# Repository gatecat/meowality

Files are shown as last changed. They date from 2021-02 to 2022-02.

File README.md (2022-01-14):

# Meowality - Kria SoM mixed reality
 
 - Kria K26 SoM with UltraScale+ FPGA
     + 4x 1.5GHz Cortex A53
     + 4GB PS DDR4
     + 256k UltraScale+ logic cells;
     + hard H.264/H.265 IP
 - 2x LPM035M407B 1440x1600 90fps LCDs (2x4-lane MIPI DSI)
 - 2x 4-lane Pi cam connector intended for iMX477 (4k 60fps+)
 - 4-lane mini-Displayport connector on fabric GTH, up to HBR3/DP1.4
 - 2-lane M.2 connector for WiFi module on PS GTR
 - USB type-C connector with USB 2 PHY on PS MIO and USB 3 on PS GTR
 - USB PD power
 - ICM-20789 IMU
 - MMC5983 magnetometer
 - microSD card
 - 5x RGB LED
 - JTAG & UART on Harting 10B-1 connector

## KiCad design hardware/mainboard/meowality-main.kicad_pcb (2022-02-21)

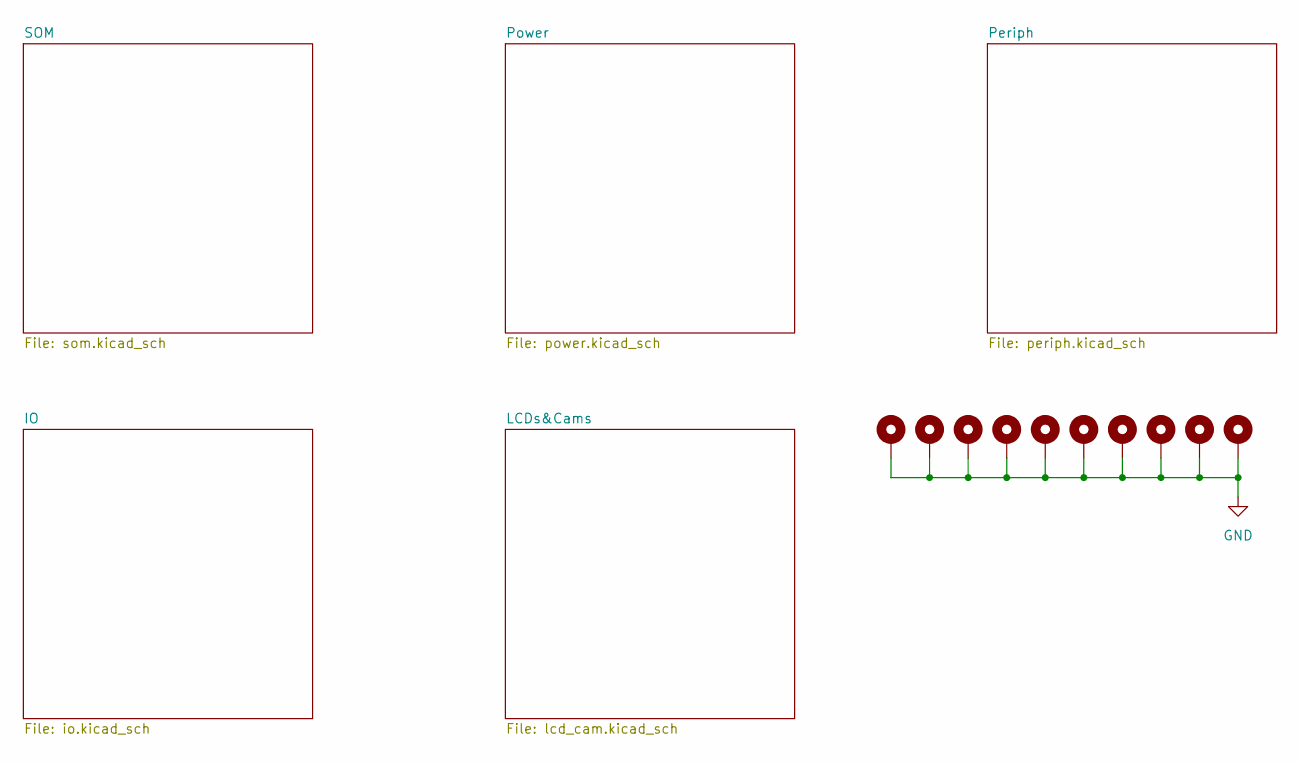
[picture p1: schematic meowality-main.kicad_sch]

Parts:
H1, H2, H3, H4, H5, H6, H7, H8, H9, H10: MountingHole_Pad; MountingHole_2.7mm_M2.5_Pad_Via

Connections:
GND: H1.1, H2.1, H3.1, H4.1, H5.1, H6.1, H7.1, H8.1, H9.1, H10.1; also elsewhere on the board

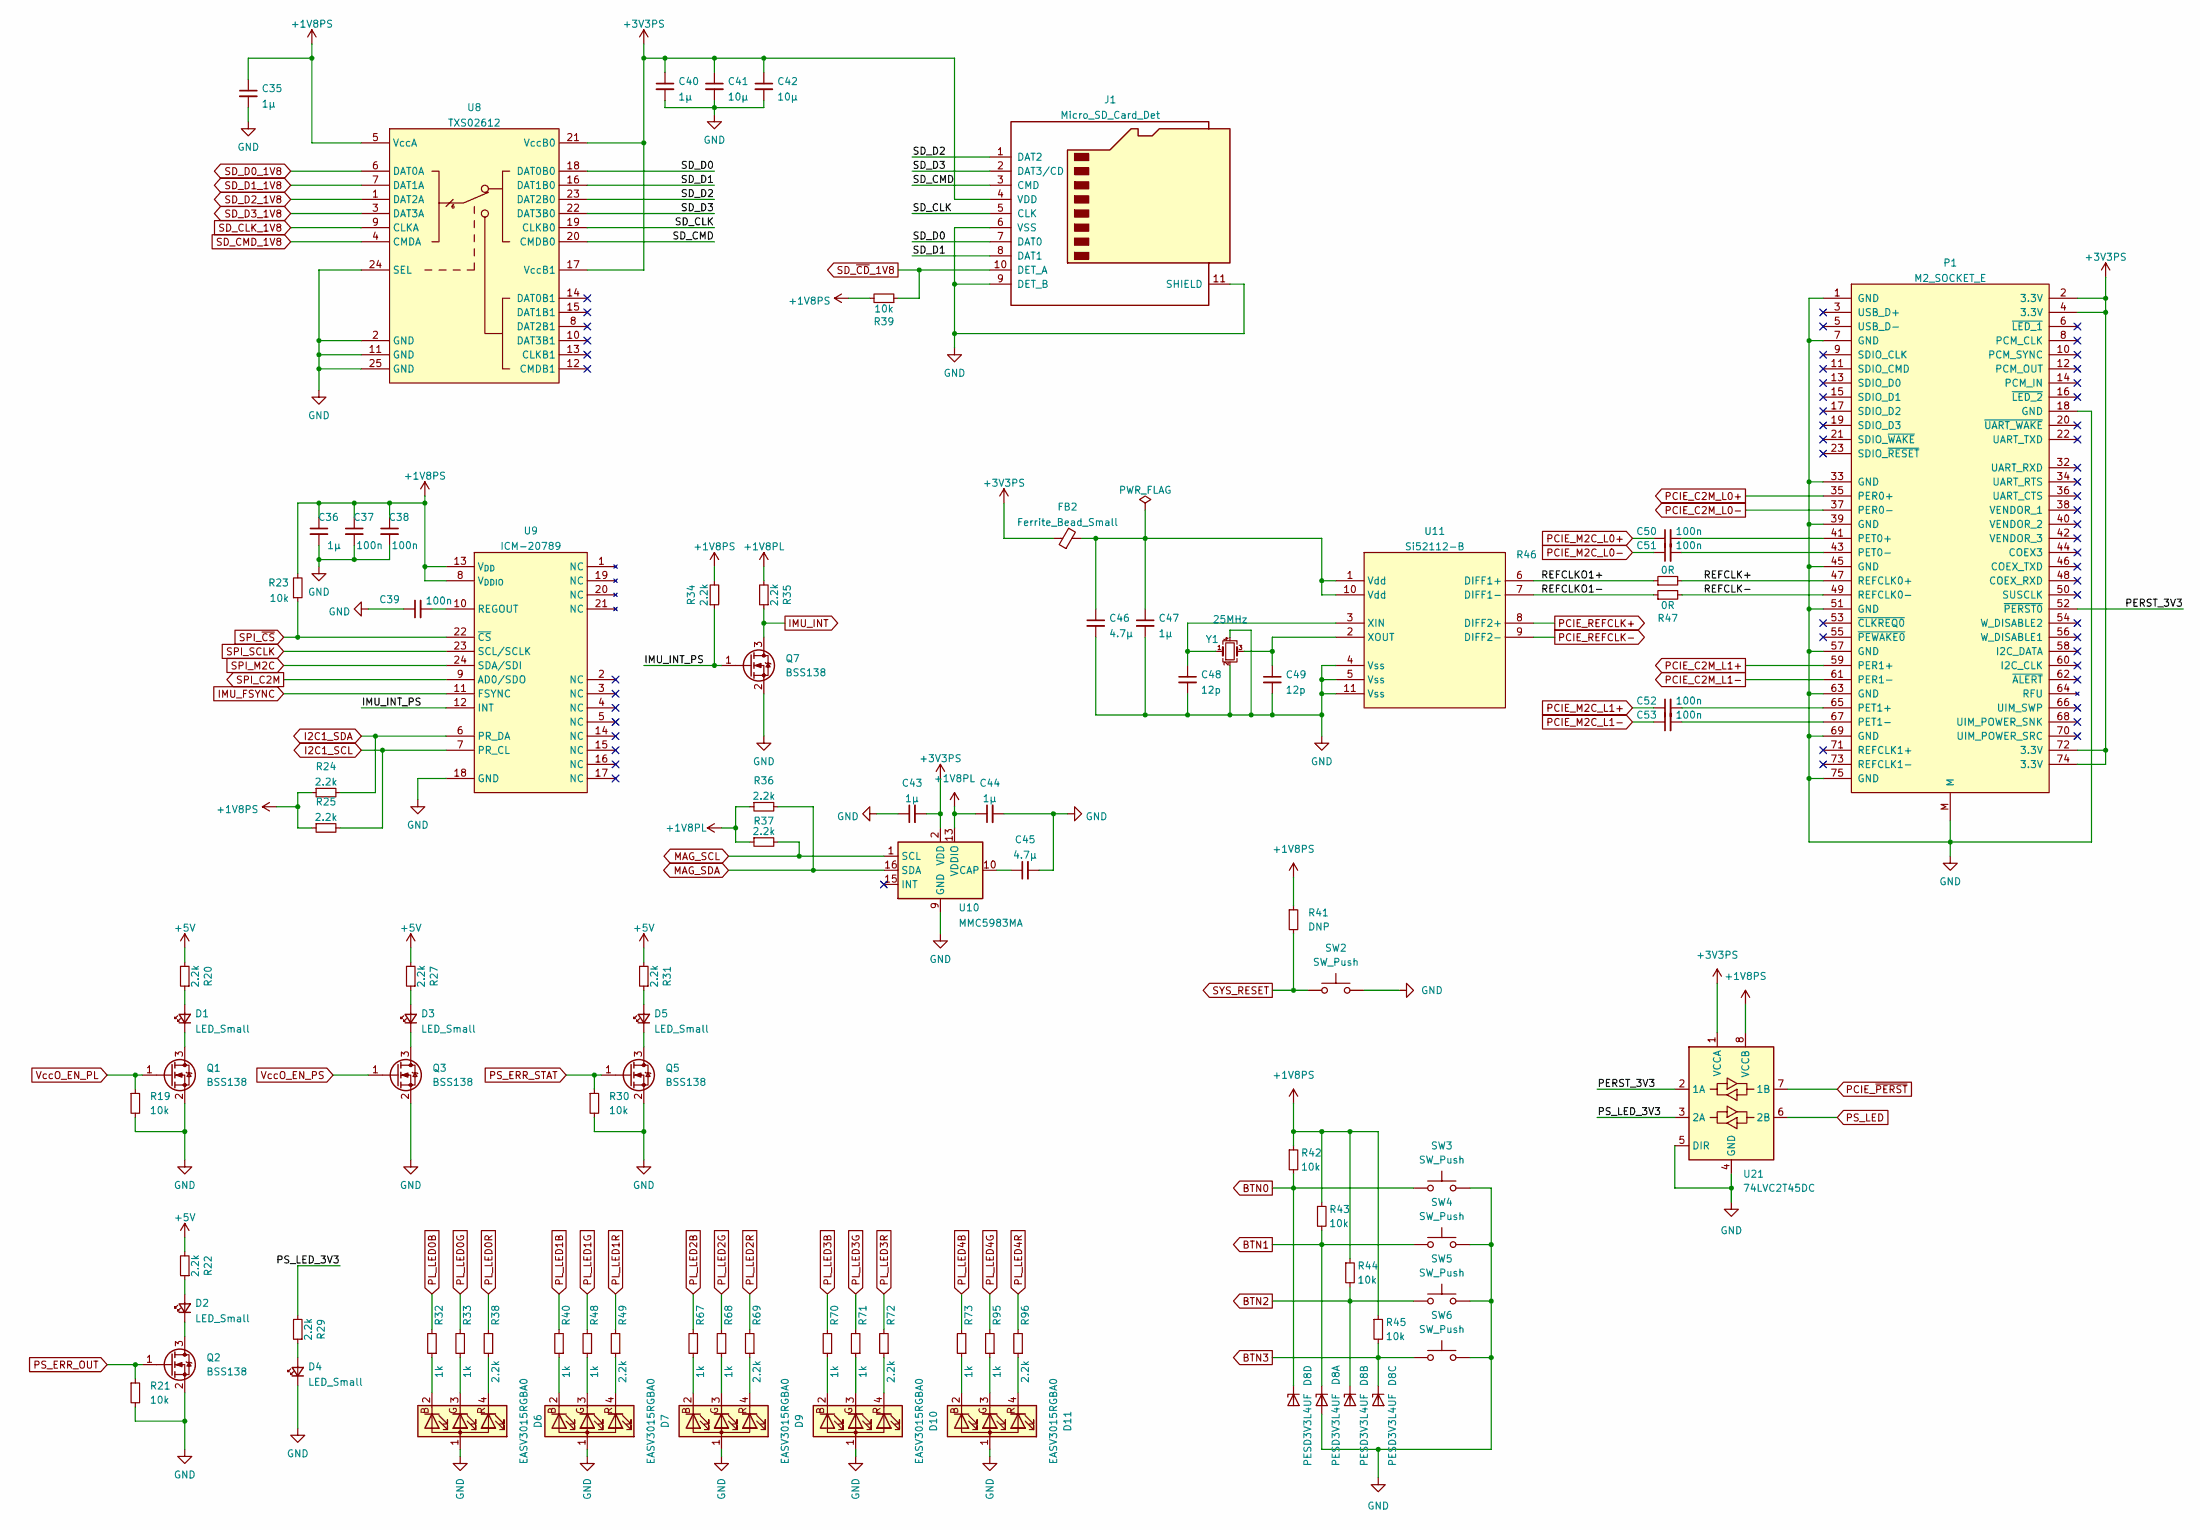
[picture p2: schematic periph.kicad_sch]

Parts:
C35, C36, C40, C43, C44, C47: 1µ; C_0603_1608Metric
C37, C38, C39, C50, C51, C52, C53: 100n; C_0402_1005Metric
C41, C42: 10µ; C_1206_3216Metric
C45, C46: 4.7µ; C_0603_1608Metric
C48, C49: 12p; C_0402_1005Metric
D1, D2, D3, D4, D5: LED_Small; LED_0603_1608Metric
D6, D7, D9, D10, D11: EASV3015RGBA0; EASV3015R
D8: PESD3V3L4UF; SOT-886
FB2: Ferrite_Bead_Small; L_0603_1608Metric
J1: Micro_SD_Card_Det; microSD_HC_Hirose_DM3AT-SF-PEJM5
P1: M2_SOCKET_E; 2199230-4
Q1, Q2, Q3, Q5, Q7: BSS138; SOT-23
R19, R21, R23, R30, R39, R42, R43, R44, R45: 10k; R_0402_1005Metric
R20, R22, R24, R25, R27, R29, R31, R34, R35, R36, R37, R38, R49, R69, R72, R96: 2.2k; R_0402_1005Metric
R32, R33, R40, R48, R67, R68, R70, R71, R73, R95: 1k; R_0402_1005Metric
R41: DNP; R_0402_1005Metric
R46, R47: 0R; R_0402_1005Metric
SW2, SW3, SW4, SW5, SW6: SW_Push; SW_SPST_B3S-1000
U8: TXS02612; WQFN-24-1EP_4x4mm_P0.5mm_EP2.45x2.45mm
U9: ICM-20789; InvenSense_QFN-24_4x4mm_P0.5mm
U10: MMC5983MA; LGA-16_3x3mm_P0.5mm
U11: Si52112-B; TDFN10_3x3mm_p0.5mm
U21: 74LVC2T45DC; X2SON-8_1.4x1mm_P0.35mm
Y1: 25MHz; Crystal_SMD_3225-4Pin_3.2x2.5mm

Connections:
+1V8PL: C44.1, R35.2, R36.1, R37.1, U10.13 (VDDIO); also elsewhere on the board
+1V8PS: C35.1, C36.1, C37.1, C38.1, R23.2, R24.1, R25.1, R34.2, R39.2, R41.1, R42.1, R43.1, R44.1, R45.1, U8.5 (VccA), U9.8 (V_{DDIO}), U9.13 (V_{DD}), U21.8 (VCCB); also elsewhere on the board
+3V3PS: C40.1, C41.1, C42.1, C43.2, FB2.1, J1.4 (VDD), P1.2 (3.3V), P1.4 (3.3V), P1.72 (3.3V), P1.74 (3.3V), U8.17 (VccB1), U8.21 (VccB0), U10.2 (VDD), U21.1 (VCCA); also elsewhere on the board
+5V: R20.2, R22.2, R27.2, R31.2; also elsewhere on the board
/Periph/IMU_INT_PS: Q7.1 (G), R34.1, U9.12 (INT)
/Periph/PERST_3V3: P1.52 (~PERST0), U21.2 (1A)
/Periph/PS_LED_3V3: R29.2, U21.3 (2A)
/Periph/REFCLK+: P1.47 (REFCLK0+), R46.2
/Periph/REFCLK-: P1.49 (REFCLK0-), R47.2
/Periph/REFCLKO1+: R46.1, U11.6 (DIFF1+)
/Periph/REFCLKO1-: R47.1, U11.7 (DIFF1-)
/Periph/SD_CLK: J1.5 (CLK), U8.19 (CLKB0)
/Periph/SD_CMD: J1.3 (CMD), U8.20 (CMDB0)
/Periph/SD_D0: J1.7 (DAT0), U8.18 (DAT0B0)
/Periph/SD_D1: J1.8 (DAT1), U8.16 (DAT1B0)
/Periph/SD_D2: J1.1 (DAT2), U8.23 (DAT2B0)
/Periph/SD_D3: J1.2 (DAT3/CD), U8.22 (DAT3B0)
BTN0: D8.6 (K4), R42.2, SW3.1; also elsewhere on the board
BTN1: D8.1 (K1), R43.2, SW4.1; also elsewhere on the board
BTN2: D8.3 (K2), R44.2, SW5.1; also elsewhere on the board
BTN3: D8.4 (K3), R45.2, SW6.1; also elsewhere on the board
GND: C35.2, C36.2, C37.2, C38.2, C39.1, C40.2, C41.2, C42.2, C43.1, C44.2, C45.2, C46.2, C47.2, C48.2, C49.2, D4.1 (K), D6.1 (A), D7.1 (A), D8.2 (A), D8.5 (A), D9.1 (A), D10.1 (A), D11.1 (A), J1.6 (VSS), J1.9 (DET_B), J1.11 (SHIELD), P1.1 (GND), P1.7 (GND), P1.18 (GND), P1.33 (GND), P1.39 (GND), P1.45 (GND), P1.51 (GND), P1.57 (GND), P1.63 (GND), P1.69 (GND), P1.75 (GND), P1.M, Q1.2 (S), Q2.2 (S), Q3.2 (S), Q5.2 (S), Q7.2 (S), R19.2, R21.2, R30.2, SW2.2, SW3.2, SW4.2, SW5.2, SW6.2, U8.2 (GND), U8.11 (GND), U8.24 (SEL), U8.25 (GND), U9.18 (GND), U10.9 (GND), U10.11 (GND), U11.4 (Vss), U11.5 (Vss), U11.11 (Vss), U21.4 (GND), U21.5 (DIR), Y1.2, Y1.4; also elsewhere on the board
I2C1_SCL: R25.2, U9.7 (PR_CL); also elsewhere on the board
I2C1_SDA: R24.2, U9.6 (PR_DA); also elsewhere on the board
IMU_FSYNC: U9.11 (FSYNC); also elsewhere on the board
IMU_INT: Q7.3 (D), R35.1; also elsewhere on the board
MAG_SCL: R37.2, U10.1 (SCL); also elsewhere on the board
MAG_SDA: R36.2, U10.16 (SDA); also elsewhere on the board
unnamed: C39.2, U9.10 (REGOUT)
unnamed: C45.1, U10.10 (CAP)
unnamed: C46.1, C47.1, FB2.2, U11.1 (Vdd), U11.10 (Vdd)
unnamed: C48.1, U11.3 (XIN), Y1.1
unnamed: C49.1, U11.2 (XOUT), Y1.3
unnamed: C50.2, P1.41 (PET0+)
unnamed: C51.2, P1.43 (PET0-)
unnamed: C52.2, P1.65 (PET1+)
unnamed: C53.2, P1.67 (PET1-)
unnamed: D1.1 (K), Q1.3 (D)
unnamed: D1.2 (A), R20.1
unnamed: D2.1 (K), Q2.3 (D)
unnamed: D2.2 (A), R22.1
unnamed: D3.1 (K), Q3.3 (D)
unnamed: D3.2 (A), R27.1
unnamed: D4.2 (A), R29.1
unnamed: D5.1 (K), Q5.3 (D)
unnamed: D5.2 (A), R31.1
unnamed: D6.2 (BK), R32.1
unnamed: D6.3 (GK), R33.1
unnamed: D6.4 (RK), R38.1
unnamed: D7.2 (BK), R40.1
unnamed: D7.3 (GK), R48.1
unnamed: D7.4 (RK), R49.1
unnamed: D9.2 (BK), R67.1
unnamed: D9.3 (GK), R68.1
unnamed: D9.4 (RK), R69.1
unnamed: D10.2 (BK), R70.1
unnamed: D10.3 (GK), R71.1
unnamed: D10.4 (RK), R72.1
unnamed: D11.2 (BK), R73.1
unnamed: D11.3 (GK), R95.1
unnamed: D11.4 (RK), R96.1
PCIE_C2M_L0+: P1.35 (PER0+); also elsewhere on the board
PCIE_C2M_L0-: P1.37 (PER0-); also elsewhere on the board
PCIE_C2M_L1+: P1.59 (PER1+); also elsewhere on the board
PCIE_C2M_L1-: P1.61 (PER1-); also elsewhere on the board
PCIE_M2C_L0+: C50.1; also elsewhere on the board
PCIE_M2C_L0-: C51.1; also elsewhere on the board
PCIE_M2C_L1+: C52.1; also elsewhere on the board
PCIE_M2C_L1-: C53.1; also elsewhere on the board
PCIE_REFCLK+: U11.8 (DIFF2+); also elsewhere on the board
PCIE_REFCLK-: U11.9 (DIFF2-); also elsewhere on the board
PCIE_~PERST: U21.7 (1B); also elsewhere on the board
PL_LED0B: R32.2; also elsewhere on the board
PL_LED0G: R33.2; also elsewhere on the board
PL_LED0R: R38.2; also elsewhere on the board
PL_LED1B: R40.2; also elsewhere on the board
PL_LED1G: R48.2; also elsewhere on the board
PL_LED1R: R49.2; also elsewhere on the board
PL_LED2B: R67.2; also elsewhere on the board
PL_LED2G: R68.2; also elsewhere on the board
PL_LED2R: R69.2; also elsewhere on the board
PL_LED3B: R70.2; also elsewhere on the board
PL_LED3G: R71.2; also elsewhere on the board
PL_LED3R: R72.2; also elsewhere on the board
PL_LED4B: R73.2; also elsewhere on the board
PL_LED4G: R95.2; also elsewhere on the board
PL_LED4R: R96.2; also elsewhere on the board
PS_ERR_OUT: Q2.1 (G), R21.1; also elsewhere on the board
PS_ERR_STAT: Q5.1 (G), R30.1; also elsewhere on the board
PS_LED: U21.6 (2B); also elsewhere on the board
SD_CLK_1V8: U8.9 (CLKA); also elsewhere on the board
SD_CMD_1V8: U8.4 (CMDA); also elsewhere on the board
SD_D0_1V8: U8.6 (DAT0A); also elsewhere on the board
SD_D1_1V8: U8.7 (DAT1A); also elsewhere on the board
SD_D2_1V8: U8.1 (DAT2A); also elsewhere on the board
SD_D3_1V8: U8.3 (DAT3A); also elsewhere on the board
SD_~CD_1V8: J1.10 (DET_A), R39.1; also elsewhere on the board
SPI_C2M: U9.9 (AD0/SDO); also elsewhere on the board
SPI_M2C: U9.24 (SDA/SDI); also elsewhere on the board
SPI_SCLK: U9.23 (SCL/SCLK); also elsewhere on the board
SPI_~CS: R23.1, U9.22 (~CS); also elsewhere on the board
SYS_RESET: R41.2, SW2.1; also elsewhere on the board
VccO_EN_PL: Q1.1 (G), R19.1; also elsewhere on the board
VccO_EN_PS: Q3.1 (G); also elsewhere on the board

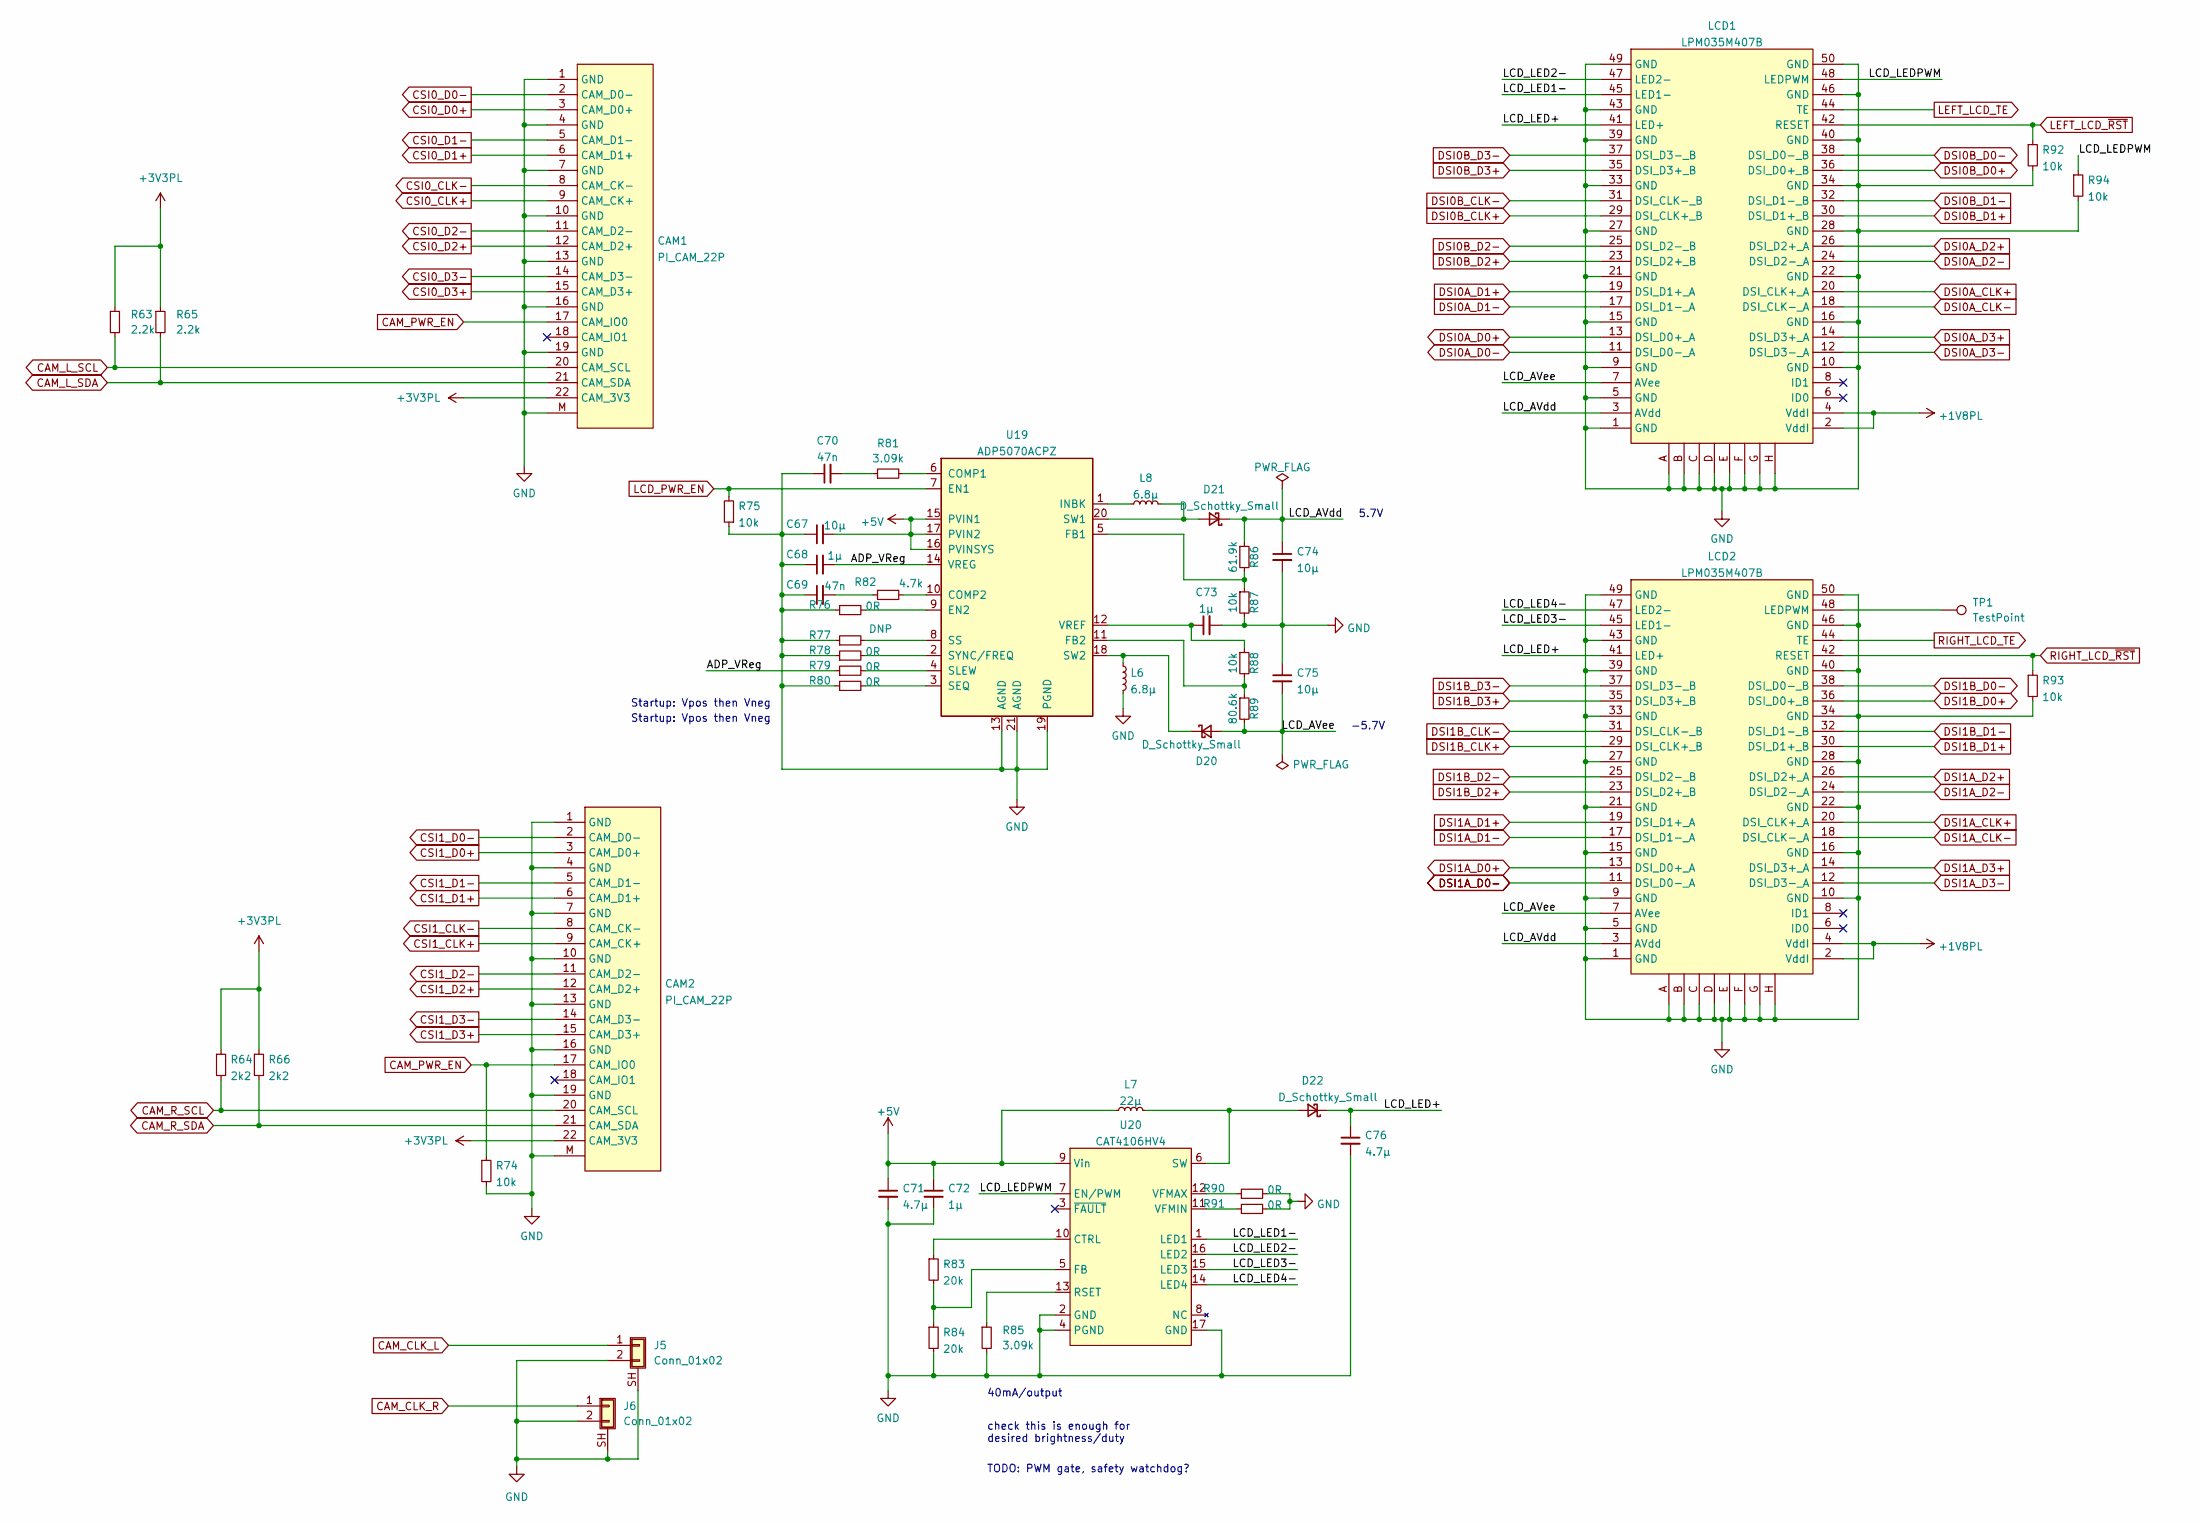
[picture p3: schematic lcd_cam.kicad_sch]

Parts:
C67, C74, C75: 10µ; C_1206_3216Metric
C68, C72, C73: 1µ; C_0603_1608Metric
C69, C70: 47n; C_0402_1005Metric
C71, C76: 4.7µ; C_0603_1608Metric
CAM1, CAM2: PI_CAM_22P; 54548-2271
D20, D21, D22: D_Schottky_Small; D_SMA
J5, J6: Conn_01x02; TE-292227-2
L6, L8: 6.8µ; L_Taiyo-Yuden_NR-50xx
L7: 22µ; L_Taiyo-Yuden_NR-50xx
LCD1, LCD2: LPM035M407B; 245863060104829
R63, R65: 2.2k; R_0402_1005Metric
R64, R66: 2k2; R_0402_1005Metric
R74, R75, R87, R88, R92, R93, R94: 10k; R_0402_1005Metric
R76, R78, R79, R80, R90, R91: 0R; R_0402_1005Metric
R77: DNP; R_0402_1005Metric
R81, R85: 3.09k; R_0402_1005Metric
R82: 4.7k; R_0402_1005Metric
R83, R84: 20k; R_0402_1005Metric
R86: 61.9k; R_0402_1005Metric
R89: 80.6k; R_0402_1005Metric
TP1: TestPoint; TestPoint_Pad_D2.0mm
U19: ADP5070ACPZ; QFN-20-1EP_4x4mm_P0.5mm_EP2.6x2.6mm
U20: CAT4106HV4; QFN-16-1EP_4x4mm_P0.65mm_EP2.1x2.1mm

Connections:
+1V8PL: LCD1.2 (VddI), LCD1.4 (VddI), LCD2.2 (VddI), LCD2.4 (VddI); also elsewhere on the board
+3V3PL: CAM1.22 (CAM_3V3), CAM2.22 (CAM_3V3), R63.1, R64.1, R65.1, R66.1; also elsewhere on the board
+5V: C67.2, C71.1, C72.1, L7.1, U19.15 (PVIN1), U19.16 (PVINSYS), U19.17 (PVIN2), U20.9 (Vin); also elsewhere on the board
/LCDs&Cams/ADP_VReg: C68.2, R79.1, U19.14 (VREG)
/LCDs&Cams/LCD_AVdd: C74.1, D21.1 (K), LCD1.3 (AVdd), LCD2.3 (AVdd), R86.1
/LCDs&Cams/LCD_AVee: C75.2, D20.2 (A), LCD1.7 (AVee), LCD2.7 (AVee), R89.2
/LCDs&Cams/LCD_LED1-: LCD1.45 (LED1-), U20.1 (LED1)
/LCDs&Cams/LCD_LED2-: LCD1.47 (LED2-), U20.16 (LED2)
/LCDs&Cams/LCD_LED3-: LCD2.45 (LED1-), U20.15 (LED3)
/LCDs&Cams/LCD_LED4-: LCD2.47 (LED2-), U20.14 (LED4)
/LCDs&Cams/LCD_LED+: C76.1, D22.1 (K), LCD1.41 (LED+), LCD2.41 (LED+)
/LCDs&Cams/LCD_LEDPWM: LCD1.48 (LEDPWM), R94.1, U20.7 (EN/PWM)
CAM_CLK_L: J5.1; also elsewhere on the board
CAM_CLK_R: J6.1; also elsewhere on the board
CAM_L_SCL: CAM1.20 (CAM_SCL), R63.2; also elsewhere on the board
CAM_L_SDA: CAM1.21 (CAM_SDA), R65.2; also elsewhere on the board
CAM_PWR_EN: CAM1.17 (CAM_IO0), CAM2.17 (CAM_IO0), R74.1; also elsewhere on the board
CAM_R_SCL: CAM2.20 (CAM_SCL), R64.2; also elsewhere on the board
CAM_R_SDA: CAM2.21 (CAM_SDA), R66.2; also elsewhere on the board
CSI0_CLK+: CAM1.9 (CAM_CK+); also elsewhere on the board
CSI0_CLK-: CAM1.8 (CAM_CK-); also elsewhere on the board
CSI0_D0+: CAM1.3 (CAM_D0+); also elsewhere on the board
CSI0_D0-: CAM1.2 (CAM_D0-); also elsewhere on the board
CSI0_D1+: CAM1.6 (CAM_D1+); also elsewhere on the board
CSI0_D1-: CAM1.5 (CAM_D1-); also elsewhere on the board
CSI0_D2+: CAM1.12 (CAM_D2+); also elsewhere on the board
CSI0_D2-: CAM1.11 (CAM_D2-); also elsewhere on the board
CSI0_D3+: CAM1.15 (CAM_D3+); also elsewhere on the board
CSI0_D3-: CAM1.14 (CAM_D3-); also elsewhere on the board
CSI1_CLK+: CAM2.9 (CAM_CK+); also elsewhere on the board
CSI1_CLK-: CAM2.8 (CAM_CK-); also elsewhere on the board
CSI1_D0+: CAM2.3 (CAM_D0+); also elsewhere on the board
CSI1_D0-: CAM2.2 (CAM_D0-); also elsewhere on the board
CSI1_D1+: CAM2.6 (CAM_D1+); also elsewhere on the board
CSI1_D1-: CAM2.5 (CAM_D1-); also elsewhere on the board
CSI1_D2+: CAM2.12 (CAM_D2+); also elsewhere on the board
CSI1_D2-: CAM2.11 (CAM_D2-); also elsewhere on the board
CSI1_D3+: CAM2.15 (CAM_D3+); also elsewhere on the board
CSI1_D3-: CAM2.14 (CAM_D3-); also elsewhere on the board
DSI0A_CLK+: LCD1.20 (DSI_CLK+_A); also elsewhere on the board
DSI0A_CLK-: LCD1.18 (DSI_CLK-_A); also elsewhere on the board
DSI0A_D0+: LCD1.13 (DSI_D0+_A); also elsewhere on the board
DSI0A_D0-: LCD1.11 (DSI_D0-_A); also elsewhere on the board
DSI0A_D1+: LCD1.19 (DSI_D1+_A); also elsewhere on the board
DSI0A_D1-: LCD1.17 (DSI_D1-_A); also elsewhere on the board
DSI0A_D2+: LCD1.26 (DSI_D2+_A); also elsewhere on the board
DSI0A_D2-: LCD1.24 (DSI_D2-_A); also elsewhere on the board
DSI0A_D3+: LCD1.14 (DSI_D3+_A); also elsewhere on the board
DSI0A_D3-: LCD1.12 (DSI_D3-_A); also elsewhere on the board
DSI0B_CLK+: LCD1.29 (DSI_CLK+_B); also elsewhere on the board
DSI0B_CLK-: LCD1.31 (DSI_CLK-_B); also elsewhere on the board
DSI0B_D0+: LCD1.36 (DSI_D0+_B); also elsewhere on the board
DSI0B_D0-: LCD1.38 (DSI_D0-_B); also elsewhere on the board
DSI0B_D1+: LCD1.30 (DSI_D1+_B); also elsewhere on the board
DSI0B_D1-: LCD1.32 (DSI_D1-_B); also elsewhere on the board
DSI0B_D2+: LCD1.23 (DSI_D2+_B); also elsewhere on the board
DSI0B_D2-: LCD1.25 (DSI_D2-_B); also elsewhere on the board
DSI0B_D3+: LCD1.35 (DSI_D3+_B); also elsewhere on the board
DSI0B_D3-: LCD1.37 (DSI_D3-_B); also elsewhere on the board
DSI1A_CLK+: LCD2.20 (DSI_CLK+_A); also elsewhere on the board
DSI1A_CLK-: LCD2.18 (DSI_CLK-_A); also elsewhere on the board
DSI1A_D0+: LCD2.13 (DSI_D0+_A); also elsewhere on the board
DSI1A_D0-: LCD2.11 (DSI_D0-_A); also elsewhere on the board
DSI1A_D1+: LCD2.19 (DSI_D1+_A); also elsewhere on the board
DSI1A_D1-: LCD2.17 (DSI_D1-_A); also elsewhere on the board
DSI1A_D2+: LCD2.26 (DSI_D2+_A); also elsewhere on the board
DSI1A_D2-: LCD2.24 (DSI_D2-_A); also elsewhere on the board
DSI1A_D3+: LCD2.14 (DSI_D3+_A); also elsewhere on the board
DSI1A_D3-: LCD2.12 (DSI_D3-_A); also elsewhere on the board
DSI1B_CLK+: LCD2.29 (DSI_CLK+_B); also elsewhere on the board
DSI1B_CLK-: LCD2.31 (DSI_CLK-_B); also elsewhere on the board
DSI1B_D0+: LCD2.36 (DSI_D0+_B); also elsewhere on the board
DSI1B_D0-: LCD2.38 (DSI_D0-_B); also elsewhere on the board
DSI1B_D1+: LCD2.30 (DSI_D1+_B); also elsewhere on the board
DSI1B_D1-: LCD2.32 (DSI_D1-_B); also elsewhere on the board
DSI1B_D2+: LCD2.23 (DSI_D2+_B); also elsewhere on the board
DSI1B_D2-: LCD2.25 (DSI_D2-_B); also elsewhere on the board
DSI1B_D3+: LCD2.35 (DSI_D3+_B); also elsewhere on the board
DSI1B_D3-: LCD2.37 (DSI_D3-_B); also elsewhere on the board
GND: C67.1, C68.1, C69.1, C70.1, C71.2, C72.2, C73.2, C74.2, C75.1, C76.2, CAM1.1 (GND), CAM1.4 (GND), CAM1.7 (GND), CAM1.10 (GND), CAM1.13 (GND), CAM1.16 (GND), CAM1.19 (GND), CAM1.M, CAM2.1 (GND), CAM2.4 (GND), CAM2.7 (GND), CAM2.10 (GND), CAM2.13 (GND), CAM2.16 (GND), CAM2.19 (GND), CAM2.M, J5.2, J5.SH (Shield), J6.2, J6.SH (Shield), L6.2, LCD1.1 (GND), LCD1.5 (GND), LCD1.9 (GND), LCD1.10 (GND), LCD1.15 (GND), LCD1.16 (GND), LCD1.21 (GND), LCD1.22 (GND), LCD1.27 (GND), LCD1.28 (GND), LCD1.33 (GND), LCD1.34 (GND), LCD1.39 (GND), LCD1.40 (GND), LCD1.43 (GND), LCD1.46 (GND), LCD1.49 (GND), LCD1.50 (GND), LCD1.A, LCD1.B, LCD1.C, LCD1.D, LCD1.E, LCD1.F, LCD1.G, LCD1.H, LCD2.1 (GND), LCD2.5 (GND), LCD2.9 (GND), LCD2.10 (GND), LCD2.15 (GND), LCD2.16 (GND), LCD2.21 (GND), LCD2.22 (GND), LCD2.27 (GND), LCD2.28 (GND), LCD2.33 (GND), LCD2.34 (GND), LCD2.39 (GND), LCD2.40 (GND), LCD2.43 (GND), LCD2.46 (GND), LCD2.49 (GND), LCD2.50 (GND), LCD2.A, LCD2.B, LCD2.C, LCD2.D, LCD2.E, LCD2.F, LCD2.G, LCD2.H, R74.2, R75.1, R76.1, R77.1, R78.1, R80.1, R84.2, R85.2, R87.2, R90.2, R91.2, R92.2, R93.2, R94.2, U19.13 (AGND), U19.19 (PGND), U19.21 (AGND), U20.2 (GND), U20.4 (PGND), U20.17 (GND); also elsewhere on the board
LCD_PWR_EN: R75.2, U19.7 (EN1); also elsewhere on the board
LEFT_LCD_TE: LCD1.44 (TE); also elsewhere on the board
LEFT_LCD_~RST: LCD1.42 (RESET), R92.1; also elsewhere on the board
unnamed: C69.2, R82.1
unnamed: C70.2, R81.1
unnamed: C73.1, R88.1, U19.12 (VREF)
unnamed: D20.1 (K), L6.1, U19.18 (SW2)
unnamed: D21.2 (A), L8.2, U19.20 (SW1)
unnamed: D22.2 (A), L7.2, U20.6 (SW)
unnamed: L8.1, U19.1 (INBK)
unnamed: LCD2.48 (LEDPWM), TP1.1
unnamed: R76.2, U19.9 (EN2)
unnamed: R77.2, U19.8 (SS)
unnamed: R78.2, U19.2 (SYNC/FREQ)
unnamed: R79.2, U19.4 (SLEW)
unnamed: R80.2, U19.3 (SEQ)
unnamed: R81.2, U19.6 (COMP1)
unnamed: R82.2, U19.10 (COMP2)
unnamed: R83.1, U20.10 (CTRL)
unnamed: R83.2, R84.1, U20.5 (FB)
unnamed: R85.1, U20.13 (RSET)
unnamed: R86.2, R87.1, U19.5 (FB1)
unnamed: R88.2, R89.1, U19.11 (FB2)
unnamed: R90.1, U20.12 (VFMAX)
unnamed: R91.1, U20.11 (VFMIN)
RIGHT_LCD_TE: LCD2.44 (TE); also elsewhere on the board
RIGHT_LCD_~RST: LCD2.42 (RESET), R93.1; also elsewhere on the board

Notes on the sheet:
40mA/output
TODO: PWM gate, safety watchdog?
check this is enough for desired brightness/duty
5.7V
Startup: Vpos then Vneg
-5.7V

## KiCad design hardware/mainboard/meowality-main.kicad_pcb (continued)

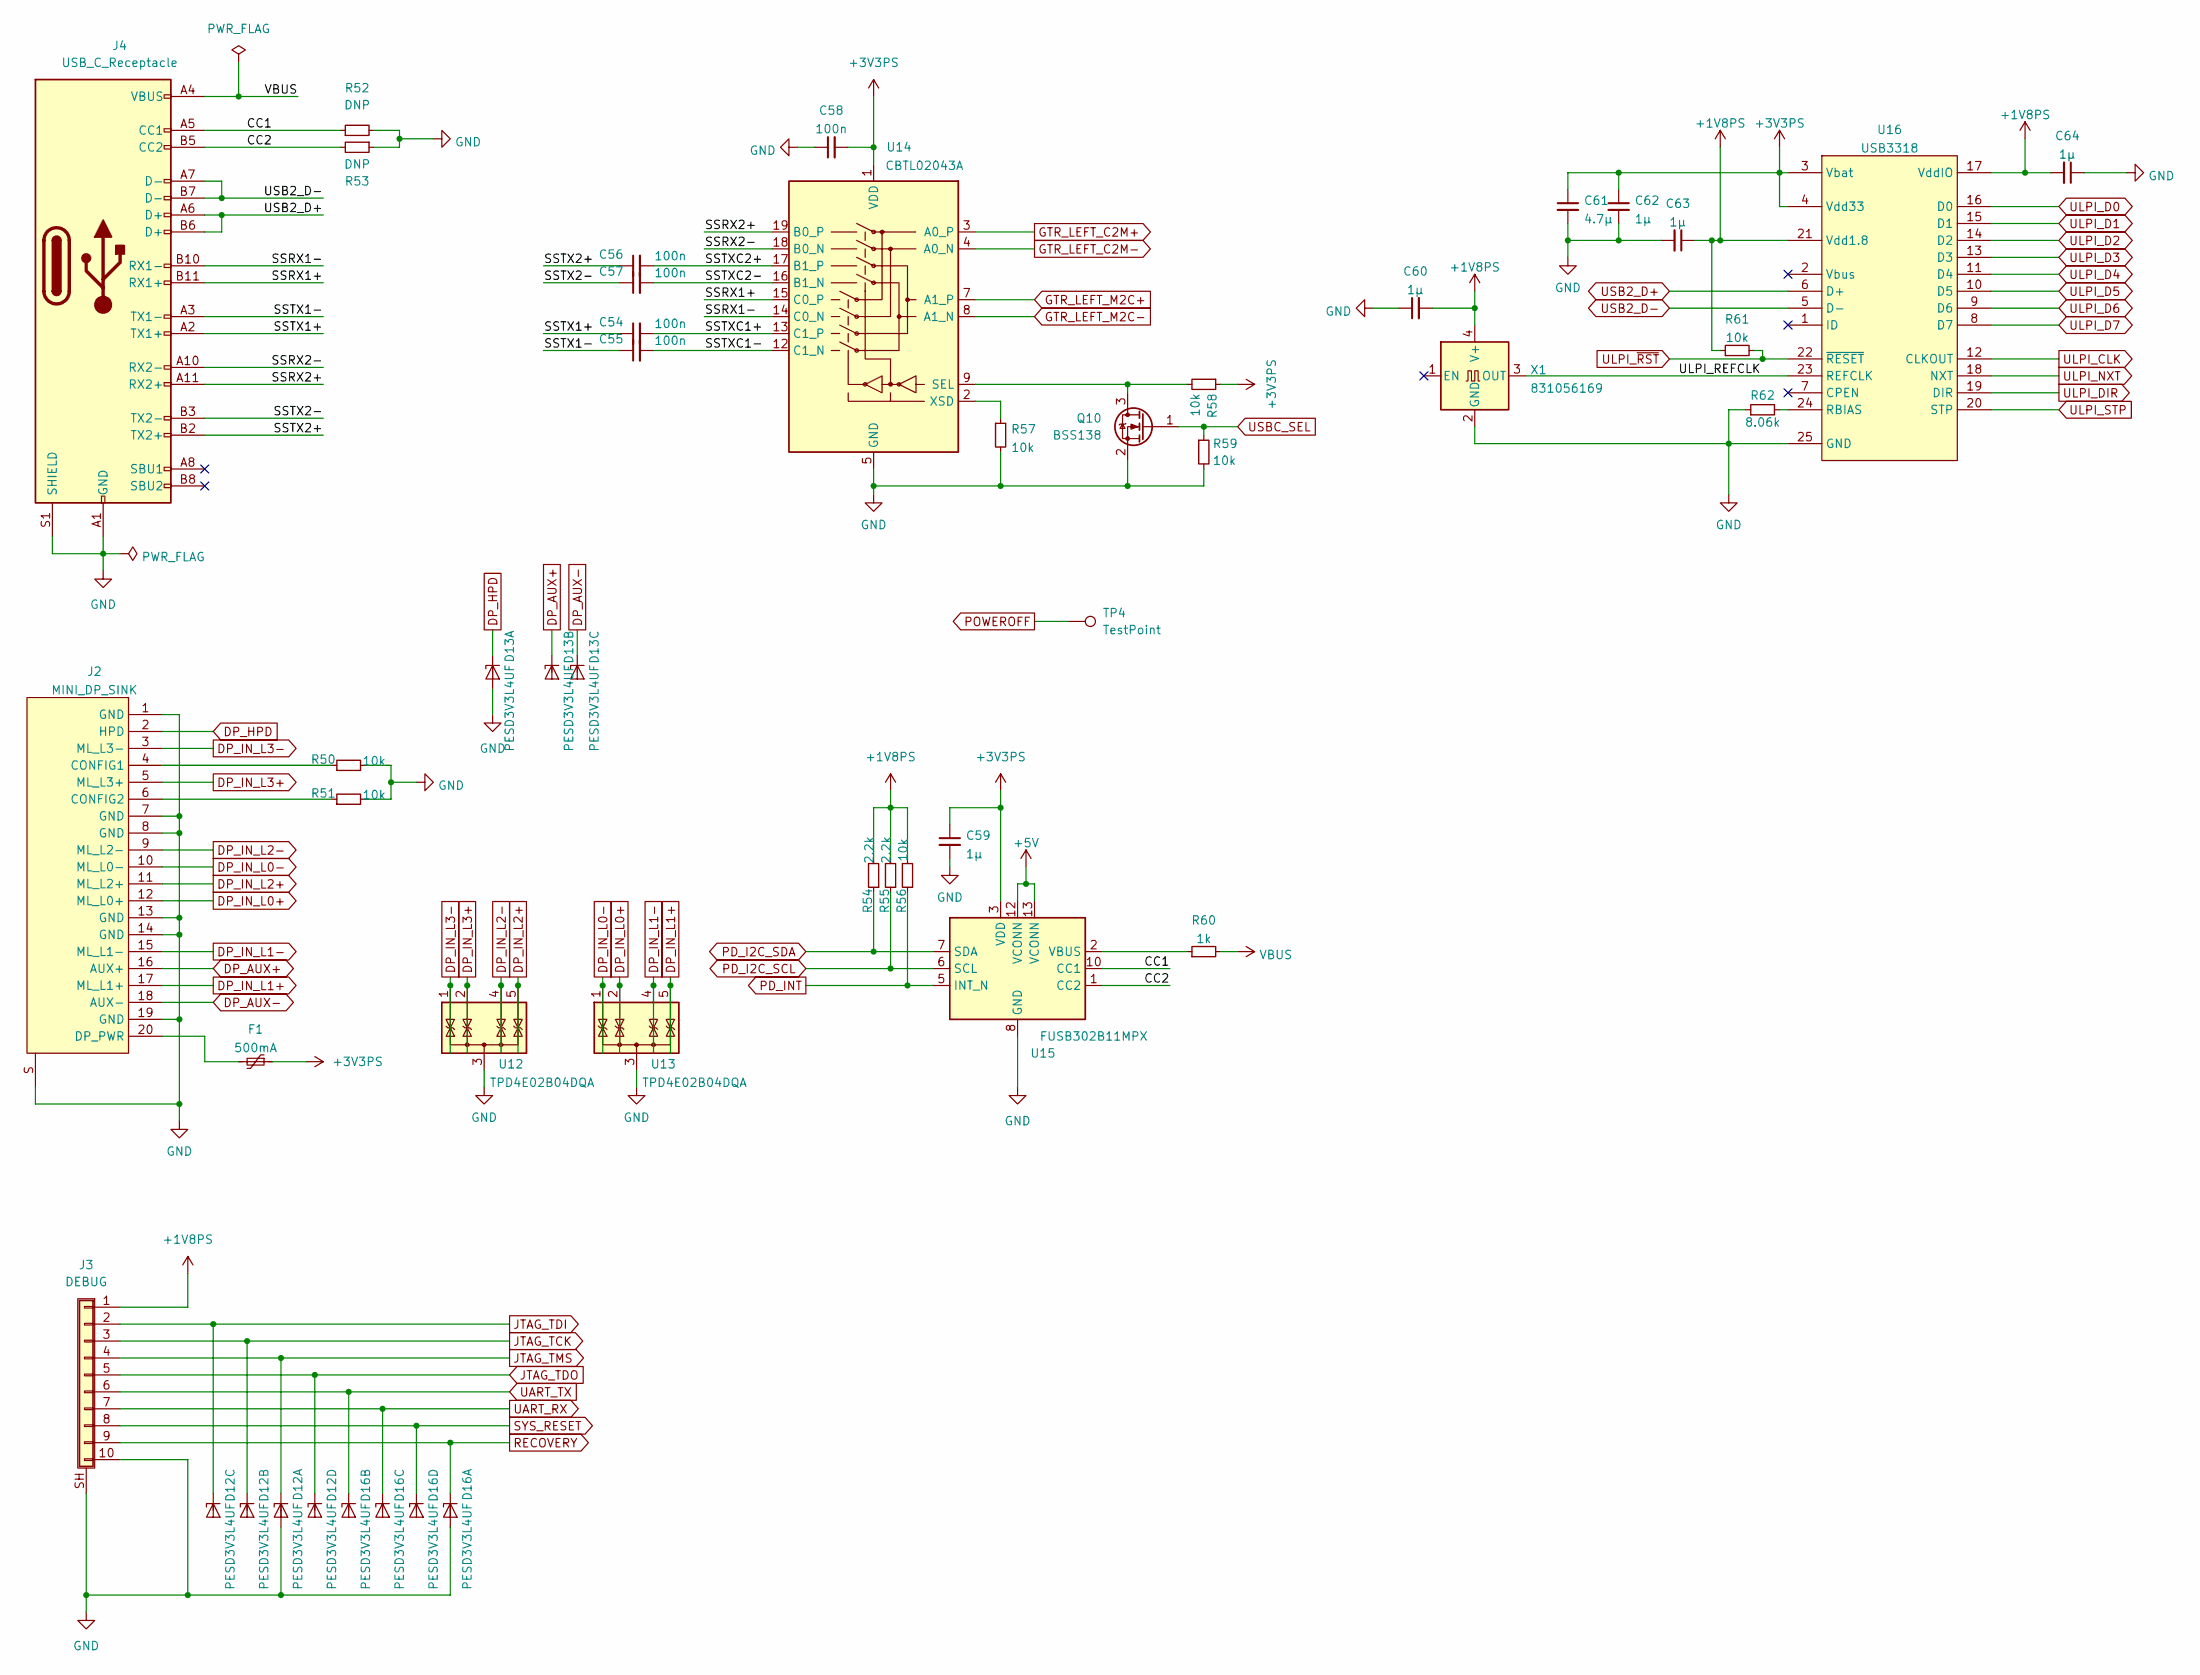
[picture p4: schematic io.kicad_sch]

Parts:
C54, C55, C56, C57, C58: 100n; C_0402_1005Metric
C59, C60, C62, C63, C64: 1µ; C_0603_1608Metric
C61: 4.7µ; C_0805_2012Metric
D12, D13, D16: PESD3V3L4UF; SOT-886
F1: 500mA; Fuse_0805_2012Metric
J2: MINI_DP_SINK; 2129320-3
J3: DEBUG; HARTING_10B1_JACK_AH
J4: USB_C_Receptacle; USB_C_Receptacle_Amphenol_12401610E4-2A
Q10: BSS138; SOT-23
R50, R51, R56, R57, R58, R59, R61: 10k; R_0402_1005Metric
R52, R53: DNP; R_0402_1005Metric
R54, R55: 2.2k; R_0402_1005Metric
R60: 1k; R_0402_1005Metric
R62: 8.06k; R_0402_1005Metric
TP4: TestPoint; TestPoint_Pad_D2.0mm
U12, U13: TPD4E02B04DQA; USON-10_2.5x1.0mm_P0.5mm
U14: CBTL02043A; WQFN-20-1EP_2.5x4.5mm_P0.5mm_EP1x2.9mm
U15: FUSB302B11MPX; WQFN-14-1EP_2.5x2.5mm_P0.5mm_EP1.45x1.45mm
U16: USB3318; HVQFN-24-1EP_4x4mm_P0.5mm_EP2.5x2.5mm
X1: 831056169; Oscillator_SMD_EuroQuartz_XO32-4Pin_3.2x2.5mm

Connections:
+1V8PS: C60.2, C63.1, C64.2, J3.1, R54.2, R55.2, R56.2, R61.1, U16.17 (VddIO), U16.21 (Vdd1.8), X1.4 (V+); also elsewhere on the board
+3V3PS: C58.2, C59.1, C61.1, C62.1, F1.1, R58.1, U14.1 (VDD), U14.6 (VDD), U14.10 (VDD), U15.3 (VDD), U15.4 (VDD), U16.3 (Vbat), U16.4 (Vdd33); also elsewhere on the board
+5V: U15.12 (VCONN), U15.13 (VCONN); also elsewhere on the board
/IO/CC1: J4.A5 (CC1), R52.1, U15.10 (CC1), U15.11 (CC1)
/IO/CC2: J4.B5 (CC2), R53.2, U15.1 (CC2), U15.14 (CC2)
/IO/SSRX1+: J4.B11 (RX1+), U14.15 (C0_P)
/IO/SSRX1-: J4.B10 (RX1-), U14.14 (C0_N)
/IO/SSRX2+: J4.A11 (RX2+), U14.19 (B0_P)
/IO/SSRX2-: J4.A10 (RX2-), U14.18 (B0_N)
/IO/SSTX1+: C54.1, J4.A2 (TX1+)
/IO/SSTX1-: C55.1, J4.A3 (TX1-)
/IO/SSTX2+: C56.1, J4.B2 (TX2+)
/IO/SSTX2-: C57.1, J4.B3 (TX2-)
/IO/SSTXC1+: C54.2, U14.13 (C1_P)
/IO/SSTXC1-: C55.2, U14.12 (C1_N)
/IO/SSTXC2+: C56.2, U14.17 (B1_P)
/IO/SSTXC2-: C57.2, U14.16 (B1_N)
/IO/ULPI_REFCLK: U16.23 (REFCLK), X1.3 (OUT)
DP_AUX+: D13.3 (K2), J2.16 (AUX+); also elsewhere on the board
DP_AUX-: D13.4 (K3), J2.18 (AUX-); also elsewhere on the board
DP_HPD: D13.1 (K1), J2.2 (HPD); also elsewhere on the board
DP_IN_L0+: J2.12 (ML_L0+), U13.2 (IO2), U13.9 (NC); also elsewhere on the board
DP_IN_L0-: J2.10 (ML_L0-), U13.1 (IO1), U13.10 (NC); also elsewhere on the board
DP_IN_L1+: J2.17 (ML_L1+), U13.5 (IO4), U13.6 (NC); also elsewhere on the board
DP_IN_L1-: J2.15 (ML_L1-), U13.4 (IO3), U13.7 (NC); also elsewhere on the board
DP_IN_L2+: J2.11 (ML_L2+), U12.5 (IO4), U12.6 (NC); also elsewhere on the board
DP_IN_L2-: J2.9 (ML_L2-), U12.4 (IO3), U12.7 (NC); also elsewhere on the board
DP_IN_L3+: J2.5 (ML_L3+), U12.2 (IO2), U12.9 (NC); also elsewhere on the board
DP_IN_L3-: J2.3 (ML_L3-), U12.1 (IO1), U12.10 (NC); also elsewhere on the board
GND: C58.1, C59.2, C60.1, C61.2, C62.2, C63.2, C64.1, D12.2 (A), D12.5 (A), D13.2 (A), D13.5 (A), D16.2 (A), D16.5 (A), J2.1 (GND), J2.7 (GND), J2.8 (GND), J2.13 (GND), J2.14 (GND), J2.19 (GND), J2.S, J3.10, J3.SH (Shield), J4.A1 (GND), J4.A12 (GND), J4.B1 (GND), J4.B12 (GND), J4.S1 (SHIELD), Q10.2 (S), R50.2, R51.2, R52.2, R53.1, R57.2, R59.2, R62.1, U12.3 (G), U12.8 (G), U13.3 (G), U13.8 (G), U14.5 (GND), U14.11 (GND), U14.20 (GND), U14.21 (GND), U15.8 (GND), U15.9 (GND), U15.15 (GND), U16.25 (GND), X1.2 (GND); also elsewhere on the board
GTR_LEFT_C2M+: U14.3 (A0_P); also elsewhere on the board
GTR_LEFT_C2M-: U14.4 (A0_N); also elsewhere on the board
GTR_LEFT_M2C+: U14.7 (A1_P); also elsewhere on the board
GTR_LEFT_M2C-: U14.8 (A1_N); also elsewhere on the board
JTAG_TCK: D12.3 (K2), J3.3; also elsewhere on the board
JTAG_TDI: D12.4 (K3), J3.2; also elsewhere on the board
JTAG_TDO: D12.6 (K4), J3.5; also elsewhere on the board
JTAG_TMS: D12.1 (K1), J3.4; also elsewhere on the board
unnamed: F1.2, J2.20 (DP_PWR)
unnamed: J2.4 (CONFIG1), R50.1
unnamed: J2.6 (CONFIG2), R51.1
unnamed: Q10.3 (D), R58.2, U14.9 (SEL)
unnamed: R57.1, U14.2 (XSD)
unnamed: R60.1, U15.2 (VBUS)
unnamed: R62.2, U16.24 (RBIAS)
PD_I2C_SCL: R55.1, U15.6 (SCL); also elsewhere on the board
PD_I2C_SDA: R54.1, U15.7 (SDA); also elsewhere on the board
PD_INT: R56.1, U15.5 (INT_N); also elsewhere on the board
POWEROFF: TP4.1; also elsewhere on the board
RECOVERY: D16.1 (K1), J3.9; also elsewhere on the board
SYS_RESET: D16.6 (K4), J3.8; also elsewhere on the board
UART_RX: D16.4 (K3), J3.7; also elsewhere on the board
UART_TX: D16.3 (K2), J3.6; also elsewhere on the board
ULPI_CLK: U16.12 (CLKOUT); also elsewhere on the board
ULPI_D0: U16.16 (D0); also elsewhere on the board
ULPI_D1: U16.15 (D1); also elsewhere on the board
ULPI_D2: U16.14 (D2); also elsewhere on the board
ULPI_D3: U16.13 (D3); also elsewhere on the board
ULPI_D4: U16.11 (D4); also elsewhere on the board
ULPI_D5: U16.10 (D5); also elsewhere on the board
ULPI_D6: U16.9 (D6); also elsewhere on the board
ULPI_D7: U16.8 (D7); also elsewhere on the board
ULPI_DIR: U16.19 (DIR); also elsewhere on the board
ULPI_NXT: U16.18 (NXT); also elsewhere on the board
ULPI_STP: U16.20 (STP); also elsewhere on the board
ULPI_~RST: R61.2, U16.22 (~RESET); also elsewhere on the board
USB2_D+: J4.A6 (D+), J4.B6 (D+), U16.6 (D+)
USB2_D-: J4.A7 (D-), J4.B7 (D-), U16.5 (D-)
USBC_SEL: Q10.1 (G), R59.1; also elsewhere on the board
VBUS: J4.A4 (VBUS), J4.A9 (VBUS), J4.B4 (VBUS), J4.B9 (VBUS), R60.2; also elsewhere on the board

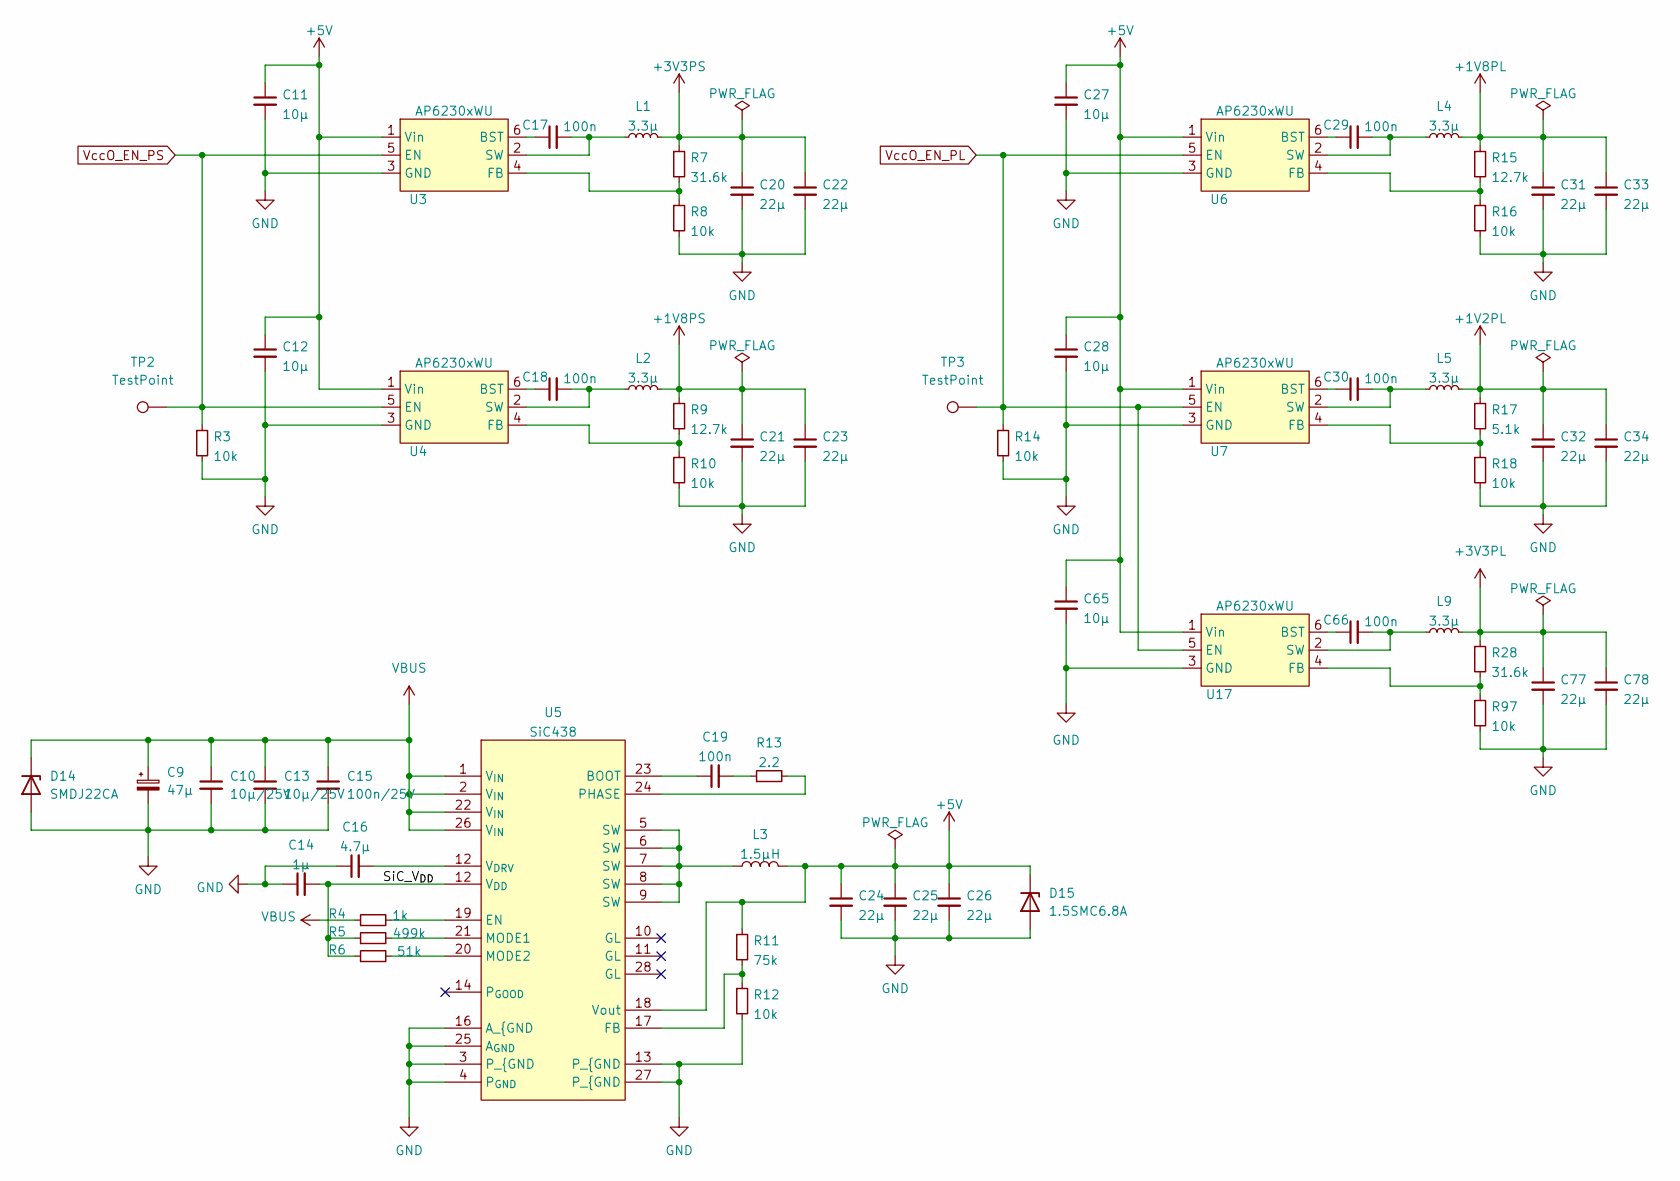
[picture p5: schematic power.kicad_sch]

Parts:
C9: 47µ; CP_Elec_6.3x3.9
C10, C13: 10µ/25V; C_1206_3216Metric
C11, C12, C27, C28, C65: 10µ; C_1206_3216Metric
C14: 1µ; C_0603_1608Metric
C15: 100n/25V; C_0805_2012Metric
C16: 4.7µ; C_0603_1608Metric
C17, C18, C19, C29, C30, C66: 100n; C_0402_1005Metric
C20, C21, C22, C23, C24, C25, C26, C31, C32, C33, C34, C77, C78: 22µ; C_1206_3216Metric
D14: SMDJ22CA; D_SMC
D15: 1.5SMC6.8A; D_SMC
L1, L2, L4, L5, L9: 3.3µ; BWVS00606045
L3: 1.5µH; L_Bourns_SRP7028A_7.3x6.6mm
R3, R8, R10, R12, R14, R16, R18, R97: 10k; R_0402_1005Metric
R4: 1k; R_0402_1005Metric
R5: 499k; R_0402_1005Metric
R6: 51k; R_0402_1005Metric
R7, R28: 31.6k; R_0402_1005Metric
R9, R15: 12.7k; R_0402_1005Metric
R11: 75k; R_0402_1005Metric
R13: 2.2; R_0402_1005Metric
R17: 5.1k; R_0402_1005Metric
TP2, TP3: TestPoint; TestPoint_Pad_D2.0mm
U3, U4, U6, U7, U17: AP6230xWU; TSOT-23-6
U5: SiC438; MLP44-24L

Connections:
+1V2PL: C32.1, C34.1, L5.2, R17.1; also elsewhere on the board
+1V8PL: C31.1, C33.1, L4.2, R15.1; also elsewhere on the board
+1V8PS: C21.1, C23.1, L2.2, R9.1; also elsewhere on the board
+3V3PL: C77.1, C78.1, L9.2, R28.1; also elsewhere on the board
+3V3PS: C20.1, C22.1, L1.2, R7.1; also elsewhere on the board
+5V: C11.1, C12.1, C24.1, C25.1, C26.1, C27.1, C28.1, C65.1, D15.1 (K), L3.2, R11.1, U3.1 (Vin), U4.1 (Vin), U5.18 (Vout), U6.1 (Vin), U7.1 (Vin), U17.1 (Vin); also elsewhere on the board
GND: C9.2, C10.2, C11.2, C12.2, C13.2, C14.1, C15.2, C16.1, C20.2, C21.2, C22.2, C23.2, C24.2, C25.2, C26.2, C27.2, C28.2, C31.2, C32.2, C33.2, C34.2, C65.2, C77.2, C78.2, D14.2 (A), D15.2 (A), R3.2, R8.2, R10.2, R12.2, R14.2, R16.2, R18.2, R97.2, U3.3 (GND), U4.3 (GND), U5.3 (P_{GND), U5.4 (P_{GND}), U5.13 (P_{GND), U5.16 (A_{GND), U5.25 (A_{GND}), U5.27 (P_{GND), U6.3 (GND), U7.3 (GND), U17.3 (GND); also elsewhere on the board
unnamed: C17.1, U3.6 (BST)
unnamed: C17.2, L1.1, U3.2 (SW)
unnamed: C18.1, U4.6 (BST)
unnamed: C18.2, L2.1, U4.2 (SW)
unnamed: C19.1, U5.23 (BOOT)
unnamed: C19.2, R13.1
unnamed: C29.1, U6.6 (BST)
unnamed: C29.2, L4.1, U6.2 (SW)
unnamed: C30.1, U7.6 (BST)
unnamed: C30.2, L5.1, U7.2 (SW)
unnamed: C66.1, U17.6 (BST)
unnamed: C66.2, L9.1, U17.2 (SW)
unnamed: L3.1, U5.5 (SW), U5.6 (SW), U5.7 (SW), U5.8 (SW), U5.9 (SW)
unnamed: R4.2, U5.19 (EN)
unnamed: R5.2, U5.21 (MODE1)
unnamed: R6.2, U5.20 (MODE2)
unnamed: R7.2, R8.1, U3.4 (FB)
unnamed: R9.2, R10.1, U4.4 (FB)
unnamed: R11.2, R12.1, U5.17 (FB)
unnamed: R13.2, U5.24 (PHASE)
unnamed: R15.2, R16.1, U6.4 (FB)
unnamed: R17.2, R18.1, U7.4 (FB)
unnamed: R28.2, R97.1, U17.4 (FB)
VBUS: C9.1, C10.1, C13.1, C15.1, D14.1 (K), R4.1, U5.1 (V_{IN}), U5.2 (V_{IN}), U5.22 (V_{IN}), U5.26 (V_{IN}); also elsewhere on the board
VccO_EN_PL: R14.1, TP3.1, U6.5 (EN), U7.5 (EN), U17.5 (EN); also elsewhere on the board
VccO_EN_PS: R3.1, TP2.1, U3.5 (EN), U4.5 (EN); also elsewhere on the board

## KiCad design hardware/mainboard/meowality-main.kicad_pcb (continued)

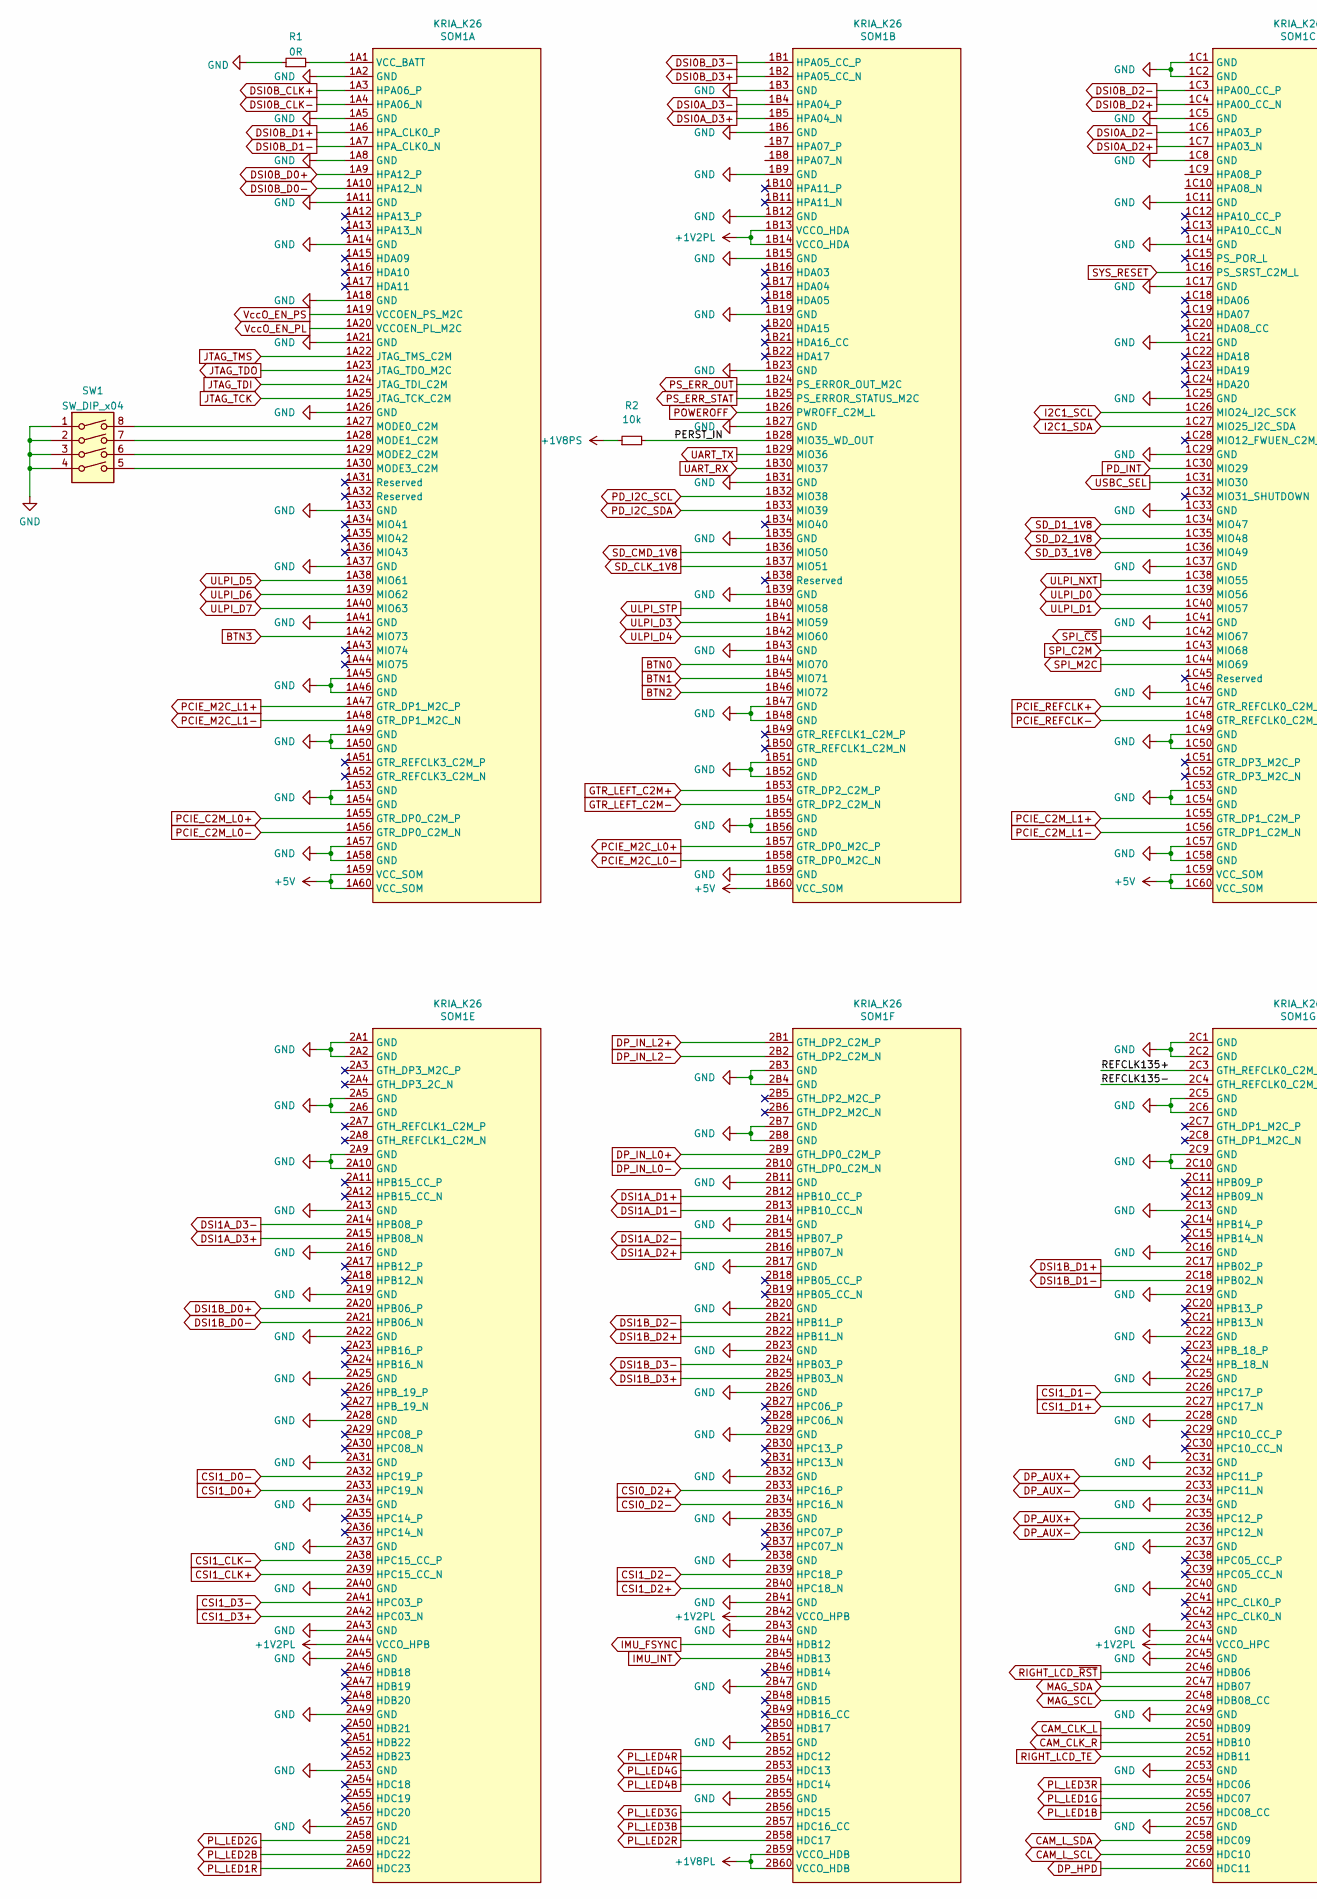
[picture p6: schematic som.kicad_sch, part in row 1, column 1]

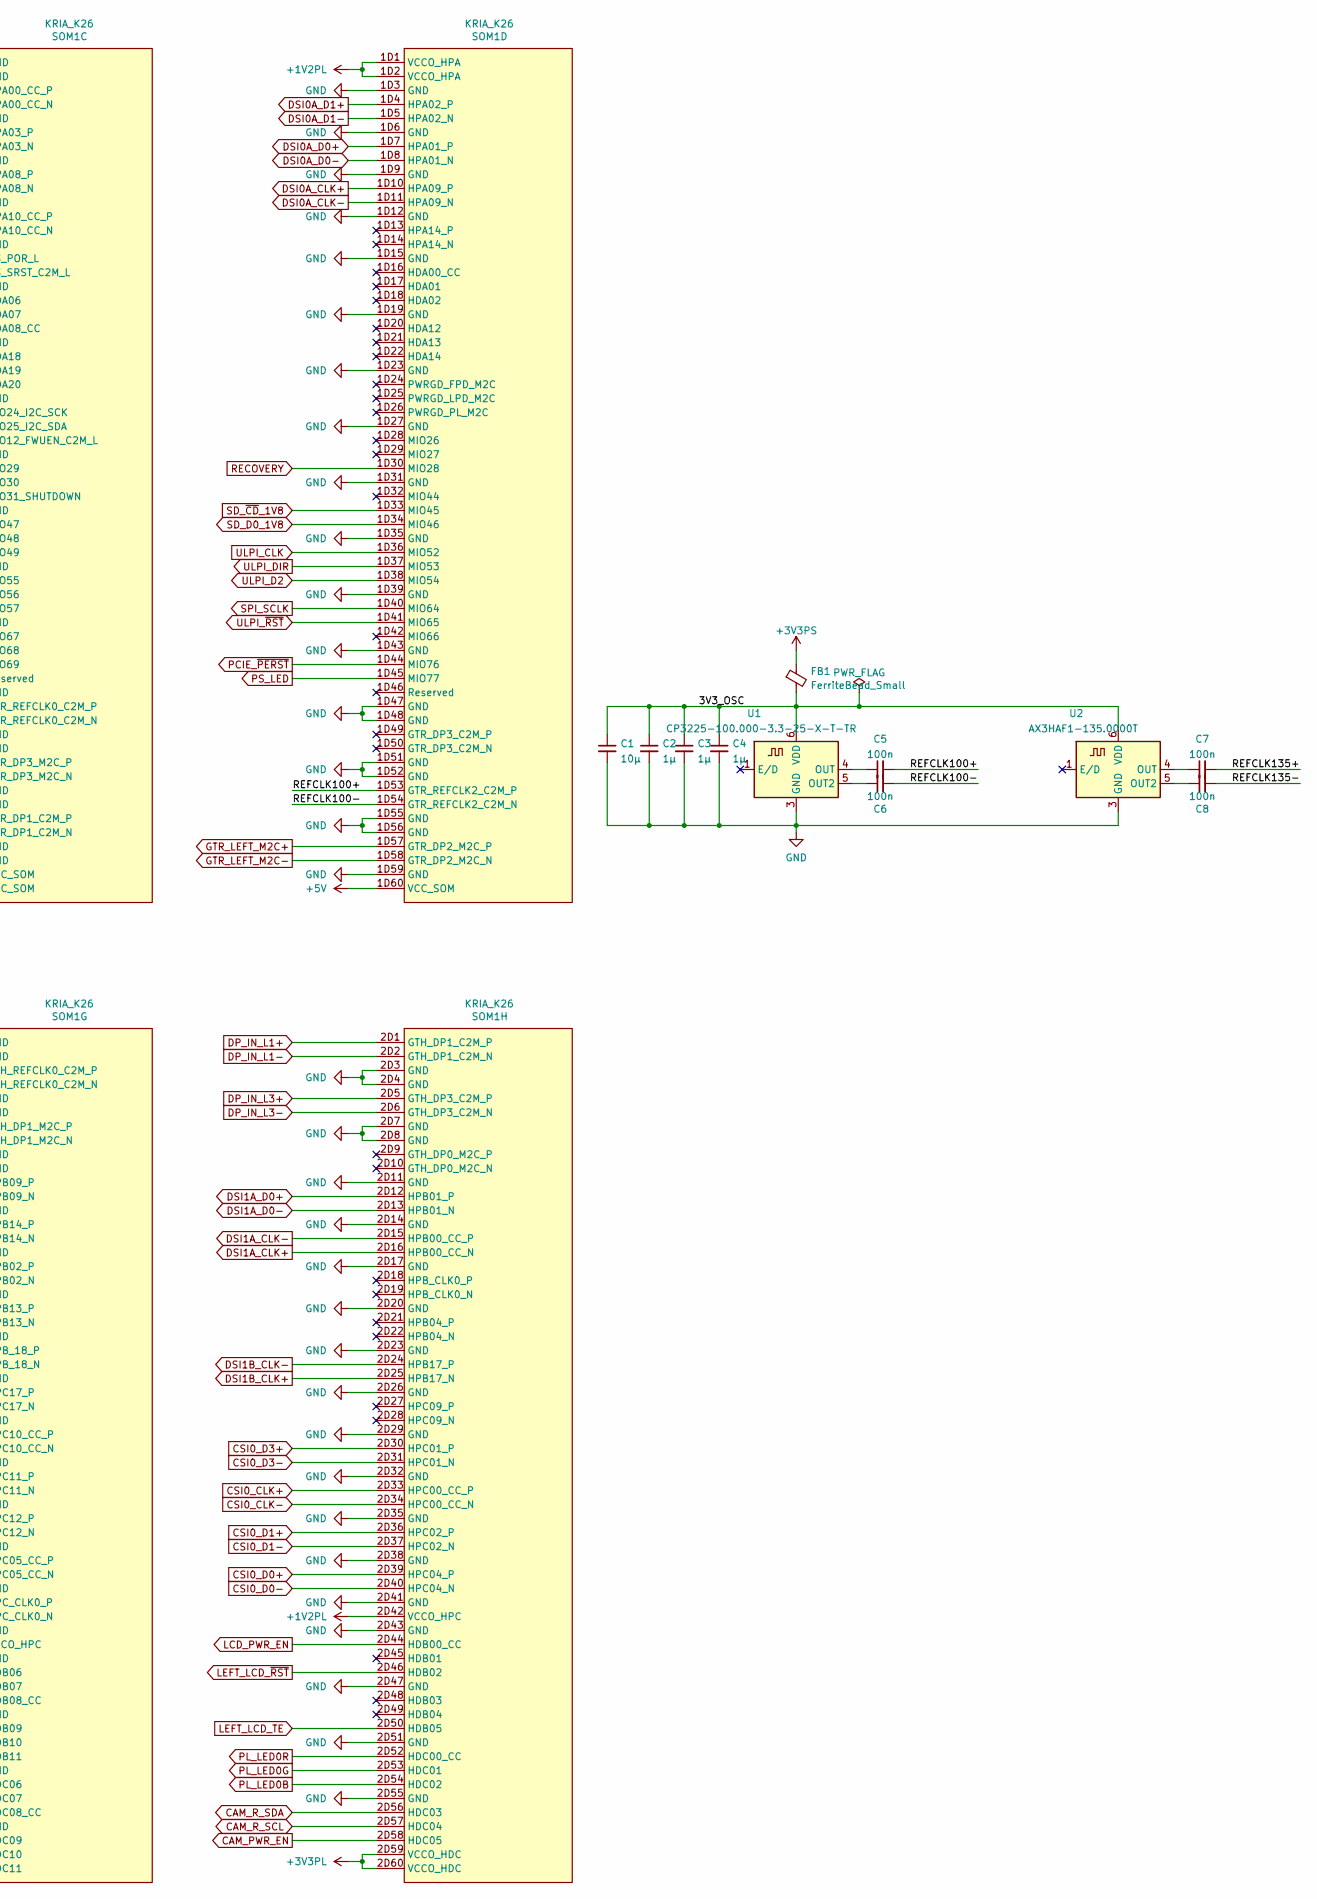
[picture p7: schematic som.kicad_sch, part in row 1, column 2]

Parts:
C1: 10µ; C_1206_3216Metric
C2, C3, C4: 1µ; C_0603_1608Metric
C5, C6, C7, C8: 100n; C_0402_1005Metric
FB1: FerriteBead_Small; L_0603_1608Metric
R1: 0R; R_0402_1005Metric
R2: 10k; R_0402_1005Metric
SOM1: KRIA_K26
SW1: SW_DIP_x04; SW_DIP_SPSTx04_Slide_Copal_CHS-04B_W7.62mm_P1.27mm
U1: CP3225-100.000-3.3-25-X-T-TR; Oscillator_SMD_IDT_JS6-6_5.0x3.2mm_P1.27mm
U2: AX3HAF1-135.0000T; Oscillator_SMD_IDT_JS6-6_5.0x3.2mm_P1.27mm

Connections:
+1V2PL: SOM1.1B13 (VCCO_HDA), SOM1.1B14 (VCCO_HDA), SOM1.1D1 (VCCO_HPA), SOM1.1D2 (VCCO_HPA), SOM1.2A44 (VCCO_HPB), SOM1.2B42 (VCCO_HPB), SOM1.2C44 (VCCO_HPC), SOM1.2D42 (VCCO_HPC); also elsewhere on the board
+1V8PL: SOM1.2B59 (VCCO_HDB), SOM1.2B60 (VCCO_HDB); also elsewhere on the board
+1V8PS: R2.1; also elsewhere on the board
+3V3PL: SOM1.2D59 (VCCO_HDC), SOM1.2D60 (VCCO_HDC); also elsewhere on the board
+3V3PS: FB1.1; also elsewhere on the board
+5V: SOM1.1A59 (VCC_SOM), SOM1.1A60 (VCC_SOM), SOM1.1B60 (VCC_SOM), SOM1.1C59 (VCC_SOM), SOM1.1C60 (VCC_SOM), SOM1.1D60 (VCC_SOM); also elsewhere on the board
/SOM/3V3_OSC: C1.1, C2.1, C3.1, C4.1, FB1.2, U1.6 (VDD), U2.6 (VDD)
/SOM/PERST_IN: R2.2, SOM1.1B28 (MIO35_WD_OUT)
/SOM/REFCLK100+: C5.2, SOM1.1D53 (GTR_REFCLK2_C2M_P)
/SOM/REFCLK100-: C6.2, SOM1.1D54 (GTR_REFCLK2_C2M_N)
/SOM/REFCLK135+: C7.2, SOM1.2C3 (GTH_REFCLK0_C2M_P)
/SOM/REFCLK135-: C8.2, SOM1.2C4 (GTH_REFCLK0_C2M_N)
BTN0: SOM1.1B44 (MIO70); also elsewhere on the board
BTN1: SOM1.1B45 (MIO71); also elsewhere on the board
BTN2: SOM1.1B46 (MIO72); also elsewhere on the board
BTN3: SOM1.1A42 (MIO73); also elsewhere on the board
CAM_CLK_L: SOM1.2C50 (HDB09); also elsewhere on the board
CAM_CLK_R: SOM1.2C51 (HDB10); also elsewhere on the board
CAM_L_SCL: SOM1.2C59 (HDC10); also elsewhere on the board
CAM_L_SDA: SOM1.2C58 (HDC09); also elsewhere on the board
CAM_PWR_EN: SOM1.2D58 (HDC05); also elsewhere on the board
CAM_R_SCL: SOM1.2D57 (HDC04); also elsewhere on the board
CAM_R_SDA: SOM1.2D56 (HDC03); also elsewhere on the board
CSI0_CLK+: SOM1.2D33 (HPC00_CC_P); also elsewhere on the board
CSI0_CLK-: SOM1.2D34 (HPC00_CC_N); also elsewhere on the board
CSI0_D0+: SOM1.2D39 (HPC04_P); also elsewhere on the board
CSI0_D0-: SOM1.2D40 (HPC04_N); also elsewhere on the board
CSI0_D1+: SOM1.2D36 (HPC02_P); also elsewhere on the board
CSI0_D1-: SOM1.2D37 (HPC02_N); also elsewhere on the board
CSI0_D2+: SOM1.2B33 (HPC16_P); also elsewhere on the board
CSI0_D2-: SOM1.2B34 (HPC16_N); also elsewhere on the board
CSI0_D3+: SOM1.2D30 (HPC01_P); also elsewhere on the board
CSI0_D3-: SOM1.2D31 (HPC01_N); also elsewhere on the board
CSI1_CLK+: SOM1.2A39 (HPC15_CC_N); also elsewhere on the board
CSI1_CLK-: SOM1.2A38 (HPC15_CC_P); also elsewhere on the board
CSI1_D0+: SOM1.2A33 (HPC19_N); also elsewhere on the board
CSI1_D0-: SOM1.2A32 (HPC19_P); also elsewhere on the board
CSI1_D1+: SOM1.2C27 (HPC17_N); also elsewhere on the board
CSI1_D1-: SOM1.2C26 (HPC17_P); also elsewhere on the board
CSI1_D2+: SOM1.2B40 (HPC18_N); also elsewhere on the board
CSI1_D2-: SOM1.2B39 (HPC18_P); also elsewhere on the board
CSI1_D3+: SOM1.2A42 (HPC03_N); also elsewhere on the board
CSI1_D3-: SOM1.2A41 (HPC03_P); also elsewhere on the board
DP_AUX+: SOM1.2C32 (HPC11_P), SOM1.2C35 (HPC12_P); also elsewhere on the board
DP_AUX-: SOM1.2C33 (HPC11_N), SOM1.2C36 (HPC12_N); also elsewhere on the board
DP_HPD: SOM1.2C60 (HDC11); also elsewhere on the board
DP_IN_L0+: SOM1.2B9 (GTH_DP0_C2M_P); also elsewhere on the board
DP_IN_L0-: SOM1.2B10 (GTH_DP0_C2M_N); also elsewhere on the board
DP_IN_L1+: SOM1.2D1 (GTH_DP1_C2M_P); also elsewhere on the board
DP_IN_L1-: SOM1.2D2 (GTH_DP1_C2M_N); also elsewhere on the board
DP_IN_L2+: SOM1.2B1 (GTH_DP2_C2M_P); also elsewhere on the board
DP_IN_L2-: SOM1.2B2 (GTH_DP2_C2M_N); also elsewhere on the board
DP_IN_L3+: SOM1.2D5 (GTH_DP3_C2M_P); also elsewhere on the board
DP_IN_L3-: SOM1.2D6 (GTH_DP3_C2M_N); also elsewhere on the board
DSI0A_CLK+: SOM1.1D10 (HPA09_P); also elsewhere on the board
DSI0A_CLK-: SOM1.1D11 (HPA09_N); also elsewhere on the board
DSI0A_D0+: SOM1.1D7 (HPA01_P); also elsewhere on the board
DSI0A_D0-: SOM1.1D8 (HPA01_N); also elsewhere on the board
DSI0A_D1+: SOM1.1D4 (HPA02_P); also elsewhere on the board
DSI0A_D1-: SOM1.1D5 (HPA02_N); also elsewhere on the board
DSI0A_D2+: SOM1.1C7 (HPA03_N); also elsewhere on the board
DSI0A_D2-: SOM1.1C6 (HPA03_P); also elsewhere on the board
DSI0A_D3+: SOM1.1B5 (HPA04_N); also elsewhere on the board
DSI0A_D3-: SOM1.1B4 (HPA04_P); also elsewhere on the board
DSI0B_CLK+: SOM1.1A3 (HPA06_P); also elsewhere on the board
DSI0B_CLK-: SOM1.1A4 (HPA06_N); also elsewhere on the board
DSI0B_D0+: SOM1.1A9 (HPA12_P); also elsewhere on the board
DSI0B_D0-: SOM1.1A10 (HPA12_N); also elsewhere on the board
DSI0B_D1+: SOM1.1A6 (HPA_CLK0_P); also elsewhere on the board
DSI0B_D1-: SOM1.1A7 (HPA_CLK0_N); also elsewhere on the board
DSI0B_D2+: SOM1.1C4 (HPA00_CC_N); also elsewhere on the board
DSI0B_D2-: SOM1.1C3 (HPA00_CC_P); also elsewhere on the board
DSI0B_D3+: SOM1.1B2 (HPA05_CC_N); also elsewhere on the board
DSI0B_D3-: SOM1.1B1 (HPA05_CC_P); also elsewhere on the board
DSI1A_CLK+: SOM1.2D16 (HPB00_CC_N); also elsewhere on the board
DSI1A_CLK-: SOM1.2D15 (HPB00_CC_P); also elsewhere on the board
DSI1A_D0+: SOM1.2D12 (HPB01_P); also elsewhere on the board
DSI1A_D0-: SOM1.2D13 (HPB01_N); also elsewhere on the board
DSI1A_D1+: SOM1.2B12 (HPB10_CC_P); also elsewhere on the board
DSI1A_D1-: SOM1.2B13 (HPB10_CC_N); also elsewhere on the board
DSI1A_D2+: SOM1.2B16 (HPB07_N); also elsewhere on the board
DSI1A_D2-: SOM1.2B15 (HPB07_P); also elsewhere on the board
DSI1A_D3+: SOM1.2A15 (HPB08_N); also elsewhere on the board
DSI1A_D3-: SOM1.2A14 (HPB08_P); also elsewhere on the board
DSI1B_CLK+: SOM1.2D25 (HPB17_N); also elsewhere on the board
DSI1B_CLK-: SOM1.2D24 (HPB17_P); also elsewhere on the board
DSI1B_D0+: SOM1.2A20 (HPB06_P); also elsewhere on the board
DSI1B_D0-: SOM1.2A21 (HPB06_N); also elsewhere on the board
DSI1B_D1+: SOM1.2C17 (HPB02_P); also elsewhere on the board
DSI1B_D1-: SOM1.2C18 (HPB02_N); also elsewhere on the board
DSI1B_D2+: SOM1.2B22 (HPB11_N); also elsewhere on the board
DSI1B_D2-: SOM1.2B21 (HPB11_P); also elsewhere on the board
DSI1B_D3+: SOM1.2B25 (HPB03_N); also elsewhere on the board
DSI1B_D3-: SOM1.2B24 (HPB03_P); also elsewhere on the board
GND: C1.2, C2.2, C3.2, C4.2, R1.1, SOM1.1A2 (GND), SOM1.1A5 (GND), SOM1.1A8 (GND), SOM1.1A11 (GND), SOM1.1A14 (GND), SOM1.1A18 (GND), SOM1.1A21 (GND), SOM1.1A26 (GND), SOM1.1A33 (GND), SOM1.1A37 (GND), SOM1.1A41 (GND), SOM1.1A45 (GND), SOM1.1A46 (GND), SOM1.1A49 (GND), SOM1.1A50 (GND), SOM1.1A53 (GND), SOM1.1A54 (GND), SOM1.1A57 (GND), SOM1.1A58 (GND), SOM1.1B3 (GND), SOM1.1B6 (GND), SOM1.1B9 (GND), SOM1.1B12 (GND), SOM1.1B15 (GND), SOM1.1B19 (GND), SOM1.1B23 (GND), SOM1.1B27 (GND), SOM1.1B31 (GND), SOM1.1B35 (GND), SOM1.1B39 (GND), SOM1.1B43 (GND), SOM1.1B47 (GND), SOM1.1B48 (GND), SOM1.1B51 (GND), SOM1.1B52 (GND), SOM1.1B55 (GND), SOM1.1B56 (GND), SOM1.1B59 (GND), SOM1.1C1 (GND), SOM1.1C2 (GND), SOM1.1C5 (GND), SOM1.1C8 (GND), SOM1.1C11 (GND), SOM1.1C14 (GND), SOM1.1C17 (GND), SOM1.1C21 (GND), SOM1.1C25 (GND), SOM1.1C29 (GND), SOM1.1C33 (GND), SOM1.1C37 (GND), SOM1.1C41 (GND), SOM1.1C46 (GND), SOM1.1C49 (GND), SOM1.1C50 (GND), SOM1.1C53 (GND), SOM1.1C54 (GND), SOM1.1C57 (GND), SOM1.1C58 (GND), SOM1.1D3 (GND), SOM1.1D6 (GND), SOM1.1D9 (GND), SOM1.1D12 (GND), SOM1.1D15 (GND), SOM1.1D19 (GND), SOM1.1D23 (GND), SOM1.1D27 (GND), SOM1.1D31 (GND), SOM1.1D35 (GND), SOM1.1D39 (GND), SOM1.1D43 (GND), SOM1.1D47 (GND), SOM1.1D48 (GND), SOM1.1D51 (GND), SOM1.1D52 (GND), SOM1.1D55 (GND), SOM1.1D56 (GND), SOM1.1D59 (GND), SOM1.2A1 (GND), SOM1.2A2 (GND), SOM1.2A5 (GND), SOM1.2A6 (GND), SOM1.2A9 (GND), SOM1.2A10 (GND), SOM1.2A13 (GND), SOM1.2A16 (GND), SOM1.2A19 (GND), SOM1.2A22 (GND), SOM1.2A25 (GND), SOM1.2A28 (GND), SOM1.2A31 (GND), SOM1.2A34 (GND), SOM1.2A37 (GND), SOM1.2A40 (GND), SOM1.2A43 (GND), SOM1.2A45 (GND), SOM1.2A49 (GND), SOM1.2A53 (GND), SOM1.2A57 (GND), SOM1.2B3 (GND), SOM1.2B4 (GND), SOM1.2B7 (GND), SOM1.2B8 (GND), SOM1.2B11 (GND), SOM1.2B14 (GND), SOM1.2B17 (GND), SOM1.2B20 (GND), SOM1.2B23 (GND), SOM1.2B26 (GND), SOM1.2B29 (GND), SOM1.2B32 (GND), SOM1.2B35 (GND), SOM1.2B38 (GND), SOM1.2B41 (GND), SOM1.2B43 (GND), SOM1.2B47 (GND), SOM1.2B51 (GND), SOM1.2B55 (GND), SOM1.2C1 (GND), SOM1.2C2 (GND), SOM1.2C5 (GND), SOM1.2C6 (GND), SOM1.2C9 (GND), SOM1.2C10 (GND), SOM1.2C13 (GND), SOM1.2C16 (GND), SOM1.2C19 (GND), SOM1.2C22 (GND), SOM1.2C25 (GND), SOM1.2C28 (GND), SOM1.2C31 (GND), SOM1.2C34 (GND), SOM1.2C37 (GND), SOM1.2C40 (GND), SOM1.2C43 (GND), SOM1.2C45 (GND), SOM1.2C49 (GND), SOM1.2C53 (GND), SOM1.2C57 (GND), SOM1.2D3 (GND), SOM1.2D4 (GND), SOM1.2D7 (GND), SOM1.2D8 (GND), SOM1.2D11 (GND), SOM1.2D14 (GND), SOM1.2D17 (GND), SOM1.2D20 (GND), SOM1.2D23 (GND), SOM1.2D26 (GND), SOM1.2D29 (GND), SOM1.2D32 (GND), SOM1.2D35 (GND), SOM1.2D38 (GND), SOM1.2D41 (GND), SOM1.2D43 (GND), SOM1.2D47 (GND), SOM1.2D51 (GND), SOM1.2D55 (GND), SW1.1, SW1.2, SW1.3, SW1.4, U1.3 (GND), U2.3 (GND); also elsewhere on the board
GTR_LEFT_C2M+: SOM1.1B53 (GTR_DP2_C2M_P); also elsewhere on the board
GTR_LEFT_C2M-: SOM1.1B54 (GTR_DP2_C2M_N); also elsewhere on the board
GTR_LEFT_M2C+: SOM1.1D57 (GTR_DP2_M2C_P); also elsewhere on the board
GTR_LEFT_M2C-: SOM1.1D58 (GTR_DP2_M2C_N); also elsewhere on the board
I2C1_SCL: SOM1.1C26 (MIO24_I2C_SCK); also elsewhere on the board
I2C1_SDA: SOM1.1C27 (MIO25_I2C_SDA); also elsewhere on the board
IMU_FSYNC: SOM1.2B44 (HDB12); also elsewhere on the board
IMU_INT: SOM1.2B45 (HDB13); also elsewhere on the board
JTAG_TCK: SOM1.1A25 (JTAG_TCK_C2M); also elsewhere on the board
JTAG_TDI: SOM1.1A24 (JTAG_TDI_C2M); also elsewhere on the board
JTAG_TDO: SOM1.1A23 (JTAG_TDO_M2C); also elsewhere on the board
JTAG_TMS: SOM1.1A22 (JTAG_TMS_C2M); also elsewhere on the board
LCD_PWR_EN: SOM1.2D44 (HDB00_CC); also elsewhere on the board
LEFT_LCD_TE: SOM1.2D50 (HDB05); also elsewhere on the board
LEFT_LCD_~RST: SOM1.2D46 (HDB02); also elsewhere on the board
MAG_SCL: SOM1.2C48 (HDB08_CC); also elsewhere on the board
MAG_SDA: SOM1.2C47 (HDB07); also elsewhere on the board
unnamed: C5.1, U1.4 (OUT)
unnamed: C6.1, U1.5 (OUT2)
unnamed: C7.1, U2.4 (OUT)
unnamed: C8.1, U2.5 (OUT2)
unnamed: R1.2, SOM1.1A1 (VCC_BATT)
unnamed: SOM1.1A27 (MODE0_C2M), SW1.8
unnamed: SOM1.1A28 (MODE1_C2M), SW1.7
unnamed: SOM1.1A29 (MODE2_C2M), SW1.6
unnamed: SOM1.1A30 (MODE3_C2M), SW1.5
PCIE_C2M_L0+: SOM1.1A55 (GTR_DP0_C2M_P); also elsewhere on the board
PCIE_C2M_L0-: SOM1.1A56 (GTR_DP0_C2M_N); also elsewhere on the board
PCIE_C2M_L1+: SOM1.1C55 (GTR_DP1_C2M_P); also elsewhere on the board
PCIE_C2M_L1-: SOM1.1C56 (GTR_DP1_C2M_N); also elsewhere on the board
PCIE_M2C_L0+: SOM1.1B57 (GTR_DP0_M2C_P); also elsewhere on the board
PCIE_M2C_L0-: SOM1.1B58 (GTR_DP0_M2C_N); also elsewhere on the board
PCIE_M2C_L1+: SOM1.1A47 (GTR_DP1_M2C_P); also elsewhere on the board
PCIE_M2C_L1-: SOM1.1A48 (GTR_DP1_M2C_N); also elsewhere on the board
PCIE_REFCLK+: SOM1.1C47 (GTR_REFCLK0_C2M_P); also elsewhere on the board
PCIE_REFCLK-: SOM1.1C48 (GTR_REFCLK0_C2M_N); also elsewhere on the board
PCIE_~PERST: SOM1.1D44 (MIO76); also elsewhere on the board
PD_I2C_SCL: SOM1.1B32 (MIO38); also elsewhere on the board
PD_I2C_SDA: SOM1.1B33 (MIO39); also elsewhere on the board
PD_INT: SOM1.1C30 (MIO29); also elsewhere on the board
PL_LED0B: SOM1.2D54 (HDC02); also elsewhere on the board
PL_LED0G: SOM1.2D53 (HDC01); also elsewhere on the board
PL_LED0R: SOM1.2D52 (HDC00_CC); also elsewhere on the board
PL_LED1B: SOM1.2C56 (HDC08_CC); also elsewhere on the board
PL_LED1G: SOM1.2C55 (HDC07); also elsewhere on the board
PL_LED1R: SOM1.2A60 (HDC23); also elsewhere on the board
PL_LED2B: SOM1.2A59 (HDC22); also elsewhere on the board
PL_LED2G: SOM1.2A58 (HDC21); also elsewhere on the board
PL_LED2R: SOM1.2B58 (HDC17); also elsewhere on the board
PL_LED3B: SOM1.2B57 (HDC16_CC); also elsewhere on the board
PL_LED3G: SOM1.2B56 (HDC15); also elsewhere on the board
PL_LED3R: SOM1.2C54 (HDC06); also elsewhere on the board
PL_LED4B: SOM1.2B54 (HDC14); also elsewhere on the board
PL_LED4G: SOM1.2B53 (HDC13); also elsewhere on the board
PL_LED4R: SOM1.2B52 (HDC12); also elsewhere on the board
POWEROFF: SOM1.1B26 (PWROFF_C2M_L); also elsewhere on the board
PS_ERR_OUT: SOM1.1B24 (PS_ERROR_OUT_M2C); also elsewhere on the board
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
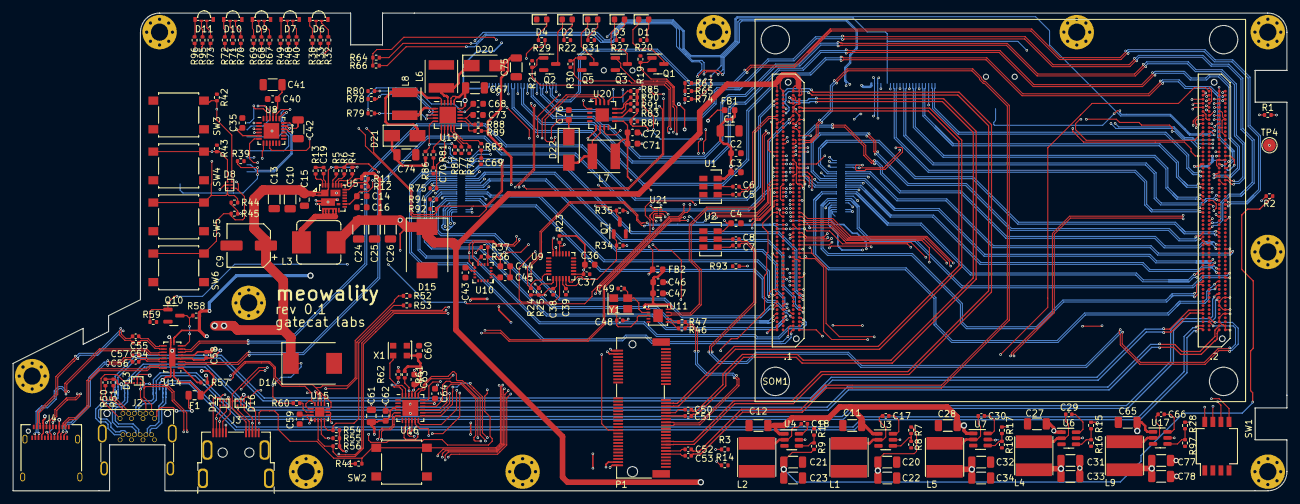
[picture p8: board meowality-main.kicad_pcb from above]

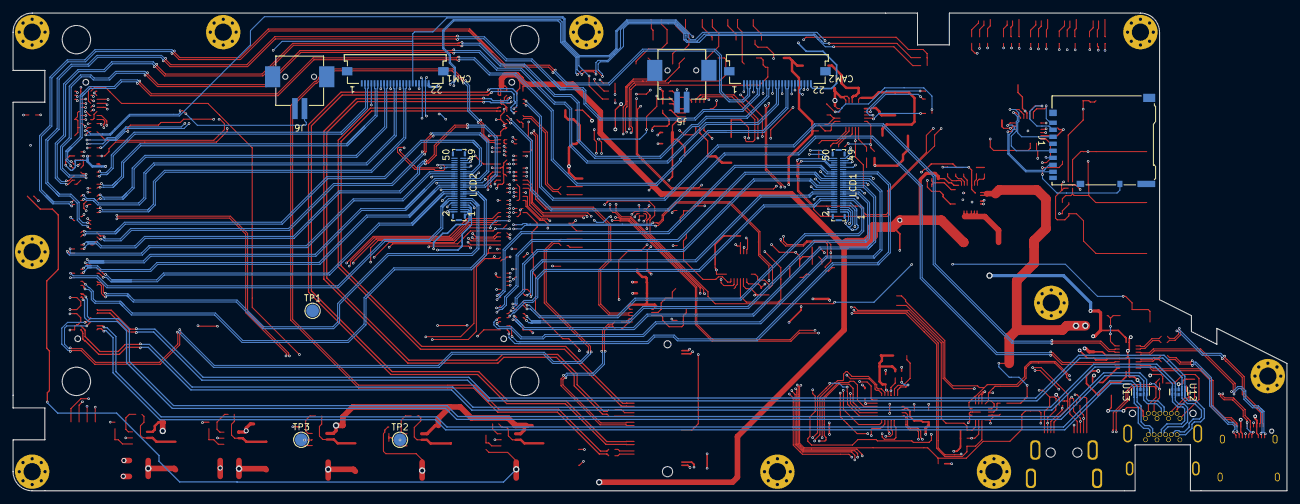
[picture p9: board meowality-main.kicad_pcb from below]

Board: 6 copper layers, 200.0 x 75.0 mm, 265 parts (12 on the bottom side), 313 nets.

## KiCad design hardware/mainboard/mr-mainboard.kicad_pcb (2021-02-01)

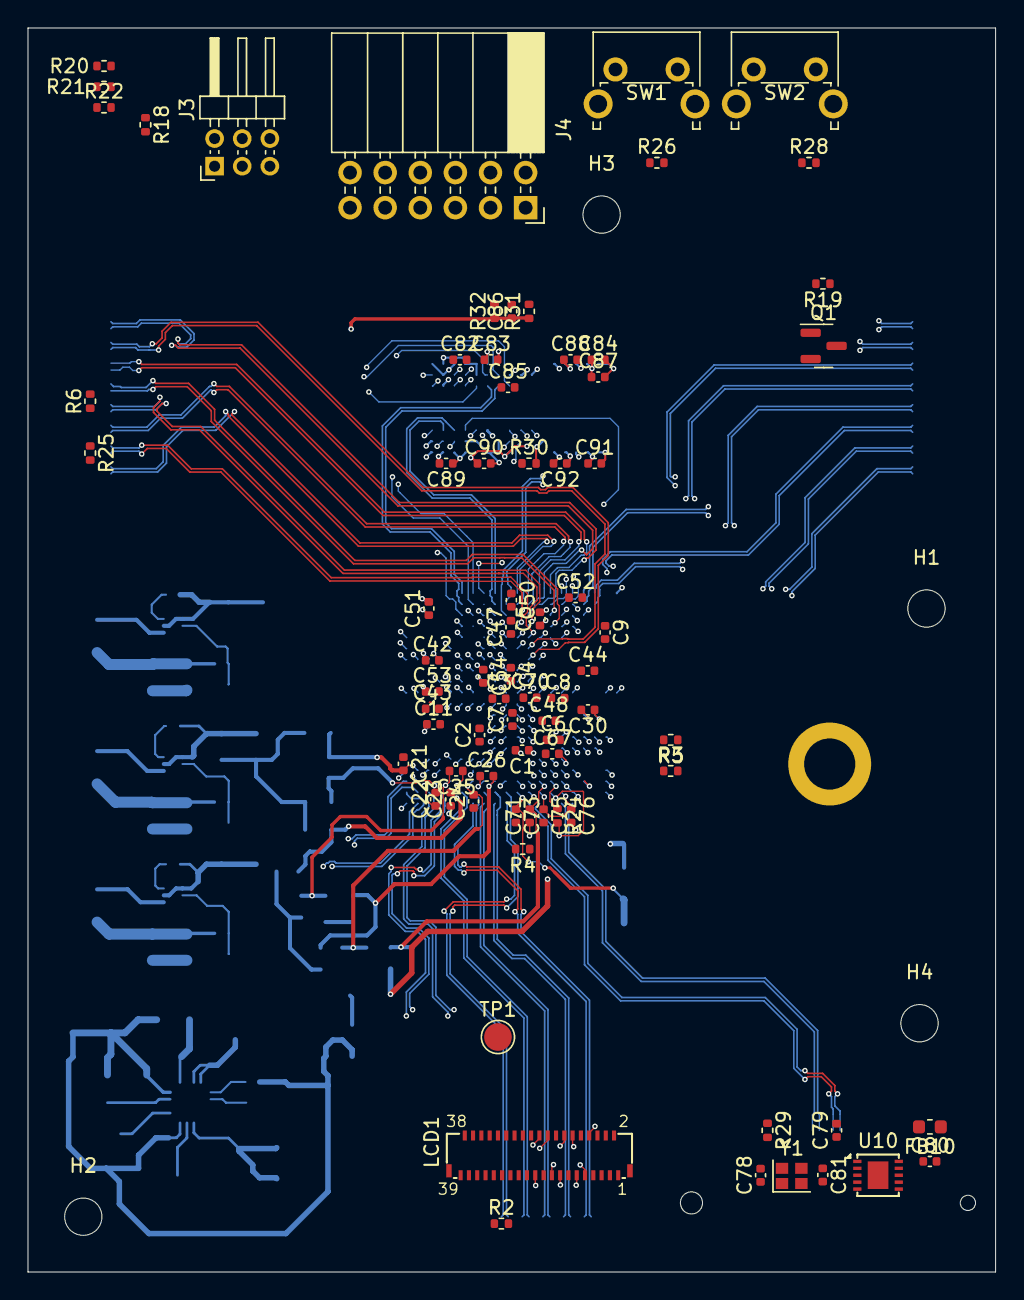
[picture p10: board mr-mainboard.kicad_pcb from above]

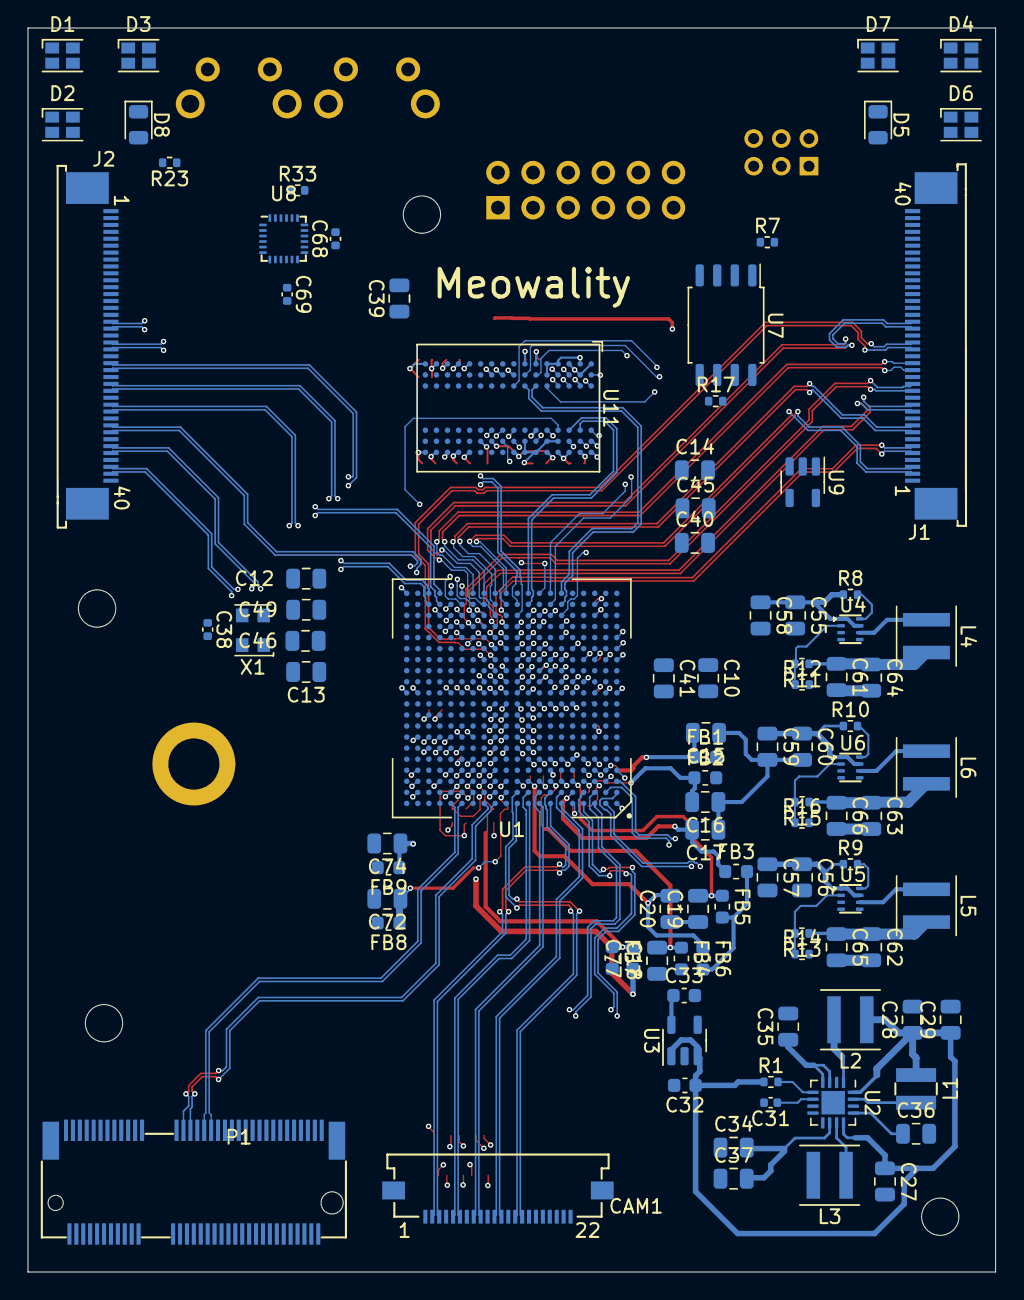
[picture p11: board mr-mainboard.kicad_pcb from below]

Board: 6 copper layers, 70.0 x 90.0 mm, 177 parts (96 on the bottom side), 193 nets.

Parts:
C1, C2, C3, C4, C5, C6, C7, C8, C9, C11, C38, C42, C43, C44, C47, C48, C50, C51, C52, C53, C54, C67, C68, C70, C79, C80, C82, C83, C84, C85, C86, C87, C88, C89, C90, C91, C92: 470n; C_0402_1005Metric
C10, C12, C13, C14, C15, C16, C17, C18, C19, C20, C27, C28, C29, C34, C35, C36, C37, C39, C40, C41, C45, C46, C49, C55, C56, C57, C58, C59, C60, C61, C62, C63, C64, C65, C66, C72, C74: 10µ; C_0805_2012Metric
C21, C22, C23, C24, C25, C26, C30, C31, C69, C71, C73, C75, C76: 100n; C_0402_1005Metric
C32, C33: 1µ; C_0603_1608Metric
C77: 2.2µ; C_0603_1608Metric
C78, C81: 12p; C_0402_1005Metric
CAM1: PI_CAM_22P; 54548-2271
D1, D2, D3, D4, D6, D7: LED_ABGR; LED_Cree-PLCC4_2x2mm_CW
D5, D8: LED_Small; LED_0805_2012Metric
FB1, FB2, FB3, FB4, FB5, FB6, FB7, FB8, FB9, FB10: 120; L_0603_1608Metric
H1, H2, H3, H4: MountingHole; MountingHole_2.7mm_M2.5
H5: MountingHole; 9774025151R
J1, J2: Conn_01x40_Shielded; TE_FPC_40pin_p0.5mm_4-1734839-0
J3: EAR; PinHeader_2x03_P2.00mm_Horizontal
J4: Conn_02x06_Top_Bottom; PinSocket_2x06_P2.54mm_Horizontal
L1: XFL3012-103MEB; XFL3012
L2, L3: XFL4020-472MEB; L_Coilcraft_XxL4020
L4, L5, L6: XFL4015-471MEB; L_Coilcraft_XxL4020
LCD1: H381Dxx0y.z; FH35C-39S-0.3SHW
P1: M2_SOCKET_E; 2199230-4
Q1: 2N7002; SOT-23
R1: 0; R_0402_1005Metric
R2, R8, R9, R10, R12, R14, R16, R17, R19, R25, R26, R28, R29, R33: 10k; R_0402_1005Metric
R3, R4, R5, R6, R7: 4.7k; R_0402_1005Metric
R11: 6.98k; R_0402_1005Metric
R13: 20k; R_0402_1005Metric
R15: 15k; R_0402_1005Metric
R18, R23, R31, R32: 1k; R_0402_1005Metric
R20, R21, R22: 220; R_0402_1005Metric
R24: 1.15k; R_0402_1005Metric
R30: NC; R_0402_1005Metric
SW1, SW2: SW_Push; SW_Tactile_SPST_Angled_PTS645Vx31-2LFS
TP1: TestPoint; TestPoint_Pad_D2.0mm
U1: LIFCL_40_CABGA400; BGA-400_20x20_17.0x17.0mm
U2: TPS65632R; QFN-16-1EP_3x3mm_P0.5mm_EP1.7x1.7mm
U3: TLV71330PDBV; SOT-23-5
U4, U5, U6: TPS62822; TI_VSON-HR_1.5x2mm_p0.5mm
U7: W25Q128JVS; SOIC-8_5.23x5.23mm_P1.27mm
U8: ICM-20948; InvenSense_QFN-24_3x3mm_P0.4mm
U9: 74AHC1G126; SOT-23-5
U10: Si52112-B; TDFN10_3x3mm_p0.5mm
U11: EM6GA16LBXA-12H; BGA-96_9.0x13.0mm_Layout2x3x16_P0.8mm
X1: XO32; Oscillator_SMD_EuroQuartz_XO32-4Pin_3.2x2.5mm
Y1: 25MHz; Crystal_SMD_2016-4Pin_2.0x1.6mm

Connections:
+1V0: C1.1, C2.1, C4.1, C6.1, C8.1, C10.1, C12.1, C61.1, C64.1, FB2.2, FB3.2, FB5.2, FB6.2, FB9.2, L4.2, R11.1, U1.F9 (VCC), U1.F12 (VCC), U1.J9 (VCC), U1.J12 (VCC), U1.L9 (VCC), U1.L12 (VCC), U1.N9 (VCC), U1.N11 (VCCECLK)
+1V5: C45.1, C47.1, C50.1, C63.1, C66.1, C82.1, C83.1, C84.1, C85.1, C87.1, C88.1, C89.1, C90.1, C91.1, C92.1, L6.2, R15.1, R32.2, U1.T9 (VCCIO4), U1.V8 (VCCIO4), U11.A1 (VddQ), U11.A8 (VddQ), U11.B2 (Vdd1), U11.C1 (VddQ), U11.C9 (VddQ), U11.D2 (VddQ), U11.D9 (Vdd1), U11.E9 (VddQ), U11.F1 (VddQ), U11.G7 (Vdd), U11.H2 (VddQ), U11.H9 (VddQ), U11.K2 (Vdd), U11.K8 (Vdd), U11.N1 (Vdd1), U11.N9 (Vdd1), U11.R1 (Vdd1), U11.R9 (Vdd1)
+1V8: C3.1, C5.1, C7.1, C9.1, C11.1, C13.1, C14.1, C41.1, C44.1, C46.1, C48.1, C49.1, C51.1, C52.1, C54.1, C62.1, C65.1, C68.1, C70.1, FB1.2, FB4.2, FB7.2, FB8.2, L5.2, LCD1.23 (IOVcc), LCD1.24 (IOVcc), R13.1, R33.2, U1.E5 (VCCIO7), U1.H3 (VCCIO7), U1.H9 (VCCAUX), U1.H12 (VCCAUXA), U1.K9 (VCCAUX), U1.K12 (VCCAUX), U1.N8 (VCCAUXH5), U1.N10 (VCCAUXH4), U1.N12 (VCCAUXH3), U1.N17 (VCCIO2), U1.U13 (VCCIO3), U1.U19 (VCCIO2), U1.V3 (VCCIO5), U1.V15 (VCCIO3), U8.8 (VDDIO), U8.13 (VDD)
+3V3: C27.1, C28.1, C29.1, C30.1, C32.1, C38.2, C39.1, C40.1, C42.1, C43.1, C53.1, C55.1, C56.1, C57.1, C58.1, C59.1, C60.1, C67.2, CAM1.22 (CAM_3V3), FB10.1, J1.37, J1.38, J1.39, J1.40, J2.1, J2.2, J2.3, J2.4, J3.1, J4.6, J4.12, L1.1, L2.1, P1.2 (3.3V), P1.4 (3.3V), P1.72 (3.3V), P1.74 (3.3V), R1.1, R3.2, R4.2, R5.1, R6.1, R7.2, R8.1, R9.1, R10.1, R18.1, R19.1, R23.1, R25.2, R26.2, R28.2, R29.1, U1.E15 (VCCIO0), U1.G17 (VCCIO1), U1.J18 (VCCIO1), U1.L3 (VCCIO6), U1.P3 (VCCIO6), U2.12 (PVin), U2.16 (AVin), U3.1 (IN), U3.3 (EN), U4.1 (EN), U4.7 (Vin), U5.1 (EN), U5.7 (Vin), U6.1 (EN), U6.7 (Vin), U7.8 (VCC), U9.5 (VCC), X1.4 (V+)
/Cam_Disp/CAM_CK+: CAM1.9 (CAM_CK+), U1.A8 (DPHY1_CKP/+)
/Cam_Disp/CAM_CK-: CAM1.8 (CAM_CK-), U1.B8 (DPHY1_CKN/-)
/Cam_Disp/CAM_D0+: CAM1.3 (CAM_D0+), U1.A7 (DPHY1_DP0/+)
/Cam_Disp/CAM_D0-: CAM1.2 (CAM_D0-), U1.B7 (DPHY1_DN0/-)
/Cam_Disp/CAM_D1+: CAM1.6 (CAM_D1+), U1.A9 (DPHY1_DP1/+)
/Cam_Disp/CAM_D1-: CAM1.5 (CAM_D1-), U1.B9 (DPHY1_DN1/-)
/Cam_Disp/CAM_D2+: CAM1.12 (CAM_D2+), U1.A6 (DPHY1_DP2/+)
/Cam_Disp/CAM_D2-: CAM1.11 (CAM_D2-), U1.B6 (DPHY1_DN2/-)
/Cam_Disp/CAM_D3+: CAM1.15 (CAM_D3+), U1.A10 (DPHY1_DP3/+)
/Cam_Disp/CAM_D3-: CAM1.14 (CAM_D3-), U1.B10 (DPHY1_DN3/-)
/Cam_Disp/DISP_AVDD_EN: LCD1.29 (AVdd_EN), U2.8 (AVddEN)
/Cam_Disp/DISP_AVdd: C36.1, LCD1.32 (AVdd), LCD1.33 (AVdd), U2.13 (OUTP2)
/Cam_Disp/DISP_CK+: LCD1.15 (CLK+), U1.A2 (DPHY0_CKP/+)
/Cam_Disp/DISP_CK-: LCD1.14 (CLK-), U1.B1 (DPHY0_CKN/-)
/Cam_Disp/DISP_D0+: LCD1.12 (D0+), U1.B2 (DPHY0_DP0/+)
/Cam_Disp/DISP_D0-: LCD1.11 (D0-), U1.C1 (DPHY0_DN0/-)
/Cam_Disp/DISP_D1+: LCD1.18 (D1+), U1.A3 (DPHY0_DP1/+)
/Cam_Disp/DISP_D1-: LCD1.17 (D1-), U1.B3 (DPHY0_DN1/-)
/Cam_Disp/DISP_D2+: LCD1.9 (D2+), U1.C2 (DPHY0_DP2/+)
/Cam_Disp/DISP_D2-: LCD1.8 (D2-), U1.D1 (DPHY0_DN2/-)
/Cam_Disp/DISP_D3+: LCD1.21 (D3+), U1.A4 (DPHY0_DP3/+)
/Cam_Disp/DISP_D3-: LCD1.20 (D3-), U1.B4 (DPHY0_DN3/-)
/Cam_Disp/DISP_OVdd: C35.1, LCD1.4 (OVdd), LCD1.5 (OVdd), LCD1.6 (OVdd), LCD1.34 (OVdd), LCD1.35 (OVdd), LCD1.36 (OVdd), U2.3 (OUTP1), U2.4 (FBS)
/Cam_Disp/DISP_OVss: C34.2, C37.2, LCD1.1 (OVss), LCD1.2 (OVss), LCD1.3 (OVss), LCD1.37 (OVss), LCD1.38 (OVss), LCD1.39 (OVss), U2.10 (OUTN)
/Cam_Disp/DISP_SWIRE: LCD1.28 (SWIRE), U2.9 (CTRL)
/Cam_Disp/DISP_Vci: C33.1, LCD1.25 (Vci), LCD1.26 (Vci), U3.5 (OUT)
/Connectors/SD0_REFRET: C71.1, C77.1, R24.2, U1.B14 (SD0_REFRET)
/FPGA_IO/CLK48: U1.L13 (PR17A/+/PCLKT1_2), X1.3 (OUT)
B2BL_CLKI+: J1.2, U1.W11 (PB54A/+/PCLKT3_0/VREF3_1/ADC_CP5/HS/BDQ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)
B2BL_CLKI-: J1.3, U1.Y11 (PB54B/-/PCLKC3_0/ADC_CN5/HS/BDQ60)
B2BL_CLKO+: J1.8, U1.Y12 (PB58A/+/PCLKT3_1/ADC_CP6/HS/BDQ60)
B2BL_CLKO-: J1.9, U1.W12 (PB58B/-/PCLKC3_1/ADC_CN6/HS/BDQ60)
B2BL_DI0+: J1.5, U1.V11 (PB56A/+/ADC_CP7/HS/BDQ60)
B2BL_DI0-: J1.6, U1.U11 (PB56B/-/ADC_CN7/HS/BDQ60)
B2BL_DI1+: J1.11, U1.U12 (PB62A/+/ADC_CP10/HS/BDQ60)
B2BL_DI1-: J1.12, U1.T12 (PB62B/-/ADC_CN10/HS/BDQ60)
B2BL_DI2+: J1.14, U1.V14 (PB68A/+/ADC_CP8/HS/BDQ60)
B2BL_DI2-: J1.15, U1.U14 (PB68B/-/ADC_CN8/HS/BDQ60)
B2BL_DO0+: J1.17, U1.Y13 (PB66A/+/COMP1IP/HS/BDQ60)
B2BL_DO0-: J1.18, U1.Y14 (PB66B/-/COMP1IN/HS/BDQ60)
B2BL_DO1+: J1.20, U1.R12 (PB64A/+/ADC_CP4/HS/BDQ60)
B2BL_DO1-: J1.21, U1.P12 (PB64B/-/ADC_CN4/HS/BDQ60)
B2BL_DO2+: J1.23, U1.W13 (PB60A/+/ADC_CP9/HS/BDQS60)
B2BL_DO2-: J1.24, U1.V12 (PB60B/-/ADC_CN9/HS/BDQSN60)
B2BL_MISC0: J1.31, U1.E9 (PL10B/-), U1.U1 (PB4A/+/CDR_RXP0/VREF5_1/ADC_CP0/COMP1P/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)
B2BL_MISC1: J1.32, U1.E7 (PL11A/+), U1.T1 (PB4B/-/CDR_RXN0/ADC_CN0/COMP1N/HS)
B2BL_MISC2: J1.33, U1.E8 (PL11B/-), U1.V1 (PB6A/+/PCLKT5_0/CDR_RXP1/ADC_CP1/COMP2P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)
B2BR_CLKI+: J2.33, U1.W14 (PB72A/+/PCLKT3_2/ADC_CP13/HS/BDQ76)
B2BR_CLKI-: J2.32, U1.W15 (PB72B/-/PCLKC3_2/ADC_CN13/HS/BDQ76)
B2BR_CLKO+: J2.39, U1.U15 (PB78A/+/ADC_CP11/HS/BDQ76)
B2BR_CLKO-: J2.38, U1.V16 (PB78B/-/ADC_CN11/HS/BDQ76)
B2BR_DI0+: J2.24, U1.T13 (PB74A/+/PCLKT3_3/ADC_CP14/HS/BDQ76)
B2BR_DI0-: J2.23, U1.T14 (PB74B/-/PCLKC3_3/ADC_CN14/HS/BDQ76)
B2BR_DI1+: J2.21, U1.Y15 (PB76A/+/COMP3IP/HS/BDQS76)
B2BR_DI1-: J2.20, U1.Y16 (PB76B/-/COMP3IN/HS/BDQSN76)
B2BR_DI2+: J2.18, U1.P13 (PB70A/+/COMP2IP/HS/BDQ76)
B2BR_DI2-: J2.17, U1.R13 (PB70B/-/COMP2IN/HS/BDQ76)
B2BR_DO0+: J2.36, U1.V17 (PB80A/+/ADC_CP12/HS/BDQ76)
B2BR_DO0-: J2.35, U1.U16 (PB80B/-/ADC_CN12/HS/BDQ76)
B2BR_DO1+: J2.30, U1.Y17 (PB82A/+/ADC_CP15/HS/BDQ76)
B2BR_DO1-: J2.29, U1.W17 (PB82B/-/ADC_CN15/HS/BDQ76)
B2BR_DO2+: J2.27, U1.W18 (PB84A/+/LRC_GPLL0T_IN/HS/BDQ76)
B2BR_DO2-: J2.26, U1.Y18 (PB84B/-/LRC_GPLL0C_IN/VREF3_2/HS/BDQ76)
B2BR_MISC0: J2.10, U1.E4 (PL13A/+), U1.Y2 (PB8A/+/PCLKT5_1/LLC_GPLL0T_IN/ADC_CP3/HS)
B2BR_MISC1: J2.9, U1.E3 (PL13B/-), U1.Y3 (PB8B/-/PCLKC5_1/LLC_GPLL0C_IN/ADC_CN3/HS)
B2BR_MISC2: J2.8, U1.E2 (PL15A/+), U1.R5 (PB10A/+/PCLKT5_2/ADC_CP2/COMP3P/HS)
BTN0: R26.1, SW1.2
BTN1: R28.1, SW2.2
CAM_IO0: CAM1.17 (CAM_IO0), U1.L16 (PR19A/+/PCLKT1_1)
CAM_IO1: CAM1.18 (CAM_IO1), U1.L15 (PR19B/-)
CAM_SCL: CAM1.20 (CAM_SCL), U1.L19 (PR20B/-)
CAM_SDA: CAM1.21 (CAM_SDA), U1.L20 (PR20A/+/PCLKT1_0)
DISP_~RESET: LCD1.27 (~RESET), R2.2, U1.D3 (PL8B/-)
DONE: Q1.1 (G), R19.2, U1.D12 (PT76B/-/DONE)
EAR_0: J3.2, U1.N6 (PL42A/+)
EAR_1: J3.3, U1.N7 (PL42B/-)
EAR_2: J3.4, U1.P1 (PL44A/+)
EAR_3: J3.5, U1.P2 (PL44B/-)
FLASH_CLK: R17.1, U1.E12 (PT76A/+/MCLK/PCLKT0_0), U7.6 (CLK)
FLASH_D0: U1.D13 (PT78B/-/MOSI/MD0), U7.5 (DI(IO0))
FLASH_D1: U1.D15 (PT80A/+/MISO/MD1), U7.2 (DO(IO1))
FLASH_D2: U1.D14 (PT80B/-/MD2), U7.3 (IO2)
FLASH_D3: U1.D16 (PT82A/+/MD3), U7.7 (IO3)
FLASH_~CS: R7.1, U1.E13 (PT78A/+/MCSN/PCLKT0_1), U7.1 (~CS)
GND: C1.2, C2.2, C3.2, C4.2, C5.2, C6.2, C7.2, C8.2, C9.2, C10.2, C11.2, C12.2, C13.2, C14.2, C15.1, C16.1, C17.1, C18.1, C19.1, C20.1, C21.1, C22.1, C23.1, C24.1, C25.1, C26.1, C27.2, C28.2, C29.2, C30.2, C31.2, C32.2, C33.2, C34.1, C35.2, C36.2, C37.1, C38.1, C39.2, C40.2, C41.2, C42.2, C43.2, C44.2, C45.2, C46.2, C47.2, C48.2, C49.2, C50.2, C51.2, C52.2, C53.2, C54.2, C55.2, C56.2, C57.2, C58.2, C59.2, C60.2, C61.2, C62.2, C63.2, C64.2, C65.2, C66.2, C67.1, C68.2, C69.2, C70.2, C72.2, C73.2, C74.2, C75.2, C76.2, C78.2, C79.2, C80.2, C81.2, C82.2, C83.2, C84.2, C85.2, C86.2, C87.2, C88.2, C89.2, C90.2, C91.2, C92.2, CAM1.1 (GND), CAM1.4 (GND), CAM1.7 (GND), CAM1.10 (GND), CAM1.13 (GND), CAM1.16 (GND), CAM1.19 (GND), CAM1.M, D5.1 (K), J1.1, J1.4, J1.7, J1.10, J1.13, J1.16, J1.19, J1.22, J1.25, J1.30, J1.35, J1.SH (Shield), J2.7, J2.11, J2.16, J2.19, J2.22, J2.25, J2.28, J2.31, J2.34, J2.37, J2.40, J2.SH (Shield), J3.6, J4.5, J4.11, L3.2, LCD1.7 (GND), LCD1.10 (GND), LCD1.13 (GND), LCD1.16 (GND), LCD1.19 (GND), LCD1.22 (GND), LCD1.31 (GND), LCD1.M, P1.1 (GND), P1.7 (GND), P1.18 (GND), P1.33 (GND), P1.39 (GND), P1.45 (GND), P1.51 (GND), P1.57 (GND), P1.63 (GND), P1.69 (GND), P1.75 (GND), Q1.2 (S), R2.1, R12.2, R14.2, R16.2, R17.2, R30.1, R31.2, SW1.1, SW2.1, U1.A1 (VSSADPHY), U1.A5 (VSSADPHY), U1.A11 (VSSSD), U1.A14 (VSSSD), U1.A17 (VSSSD), U1.A20 (VSSSD), U1.B12 (VSSSD), U1.B16 (VSSSD), U1.B19 (VSSSD), U1.C3 (VSSADPHY), U1.C6 (VSSADPHY), U1.C8 (VSSADPHY), U1.C10 (VSSADPHY), U1.C15 (VSSSD), U1.C17 (VSSSD), U1.C19 (VSSSD), U1.D19 (VSSSD), U1.D20 (VSSSD), U1.E1 (VSSADPHY), U1.E6 (VSS), U1.E14 (VSS), U1.F10 (VSS), U1.F11 (VSS), U1.G9 (VSS), U1.G10 (VSS), U1.G11 (VSS), U1.G12 (VSS), U1.G16 (VSS), U1.H4 (VSS), U1.H10 (VSS), U1.H11 (VSS), U1.J10 (VSS), U1.J11 (VSS), U1.J17 (VSS), U1.K10 (VSS), U1.K11 (VSS), U1.L4 (VSS), U1.L10 (VSS), U1.L11 (VSS), U1.M8 (VSS), U1.M9 (VSS), U1.M10 (VSS), U1.M11 (VSS), U1.M12 (VSS), U1.M13 (VSS), U1.N18 (VSS), U1.P4 (VSS), U1.T15 (VSS), U1.T19 (VSS), U1.U8 (VSS), U1.U9 (VSS), U1.V13 (VSS), U1.W3 (VSS), U1.W16 (VSS), U1.Y1 (VSS), U1.Y20 (VSS), U2.2 (PGND1), U2.7 (AGND), U2.14 (PGND2), U2.17 (PAD), U3.2 (GND), U4.3 (AGND), U4.5 (PGND), U5.3 (AGND), U5.5 (PGND), U6.3 (AGND), U6.5 (PGND), U7.4 (GND), U8.18 (GND), U8.20 (GND), U9.3 (GND), U10.4 (Vss), U10.5 (Vss), U10.11 (Vss), U11.A9 (Vss), U11.B1 (VssQ), U11.B3 (Vss), U11.B9 (VssQ), U11.D1 (VssQ), U11.D8 (VssQ), U11.E1 (Vss), U11.E2 (VssQ), U11.E8 (VssQ), U11.F9 (VssQ), U11.G1 (VssQ), U11.G8 (Vss), U11.G9 (VssQ), U11.J2 (Vss), U11.J8 (Vss), U11.M1 (Vss), U11.M9 (Vss), U11.P1 (Vss), U11.P9 (Vss), U11.T1 (Vss), U11.T9 (Vss), X1.2 (GND), Y1.2, Y1.4
IMU_CLK: U1.D6 (PL6A/+), U8.23 (SCL/SCLK)
IMU_DI: U1.D8 (PL4B/-), U8.24 (SDA/SDI)
IMU_DO: U1.D7 (PL4A/+), U8.9 (SDO/AD0)
IMU_FSYNC: U1.D4 (PL8A/+), U8.11 (FSYNC)
IMU_~CS: R33.1, U1.D5 (PL6B/-), U8.22 (~CS)
JTAG_TCK: J1.27, J2.14, U1.G18 (PR13A/+/TCK/SCLK)
JTAG_TDI: J1.28, U1.F17 (PR8B/-/TDI/SSI)
JTAG_TDI_R: J2.13, U1.F19 (PR10B/-/TDO/SSO), U9.2
JTAG_TDO_L: J1.29, J2.12, U9.4
JTAG_TMS: J1.26, J2.15, R6.2, U1.F15 (PR6B/-/TMS/SCSN)
LED_1: D6.1 (A), U1.K5 (PL24A/+)
LED_2: D3.1 (A), U1.K6 (PL24B/-)
LED_3: D1.1 (A), U1.K7 (PL26A/+)
LED_4: D7.1 (A), U1.K8 (PL26B/-)
LED_5: D4.1 (A), U1.L1 (PL27A/+)
LED_6: D2.1 (A), U1.L2 (PL27B/-)
LED_B: R22.2, U1.L7 (PL32A/+/PCLKT6_1)
LED_G: R21.2, U1.L6 (PL30B/-)
LED_R: R20.2, U1.L5 (PL30A/+/PCLKT6_0)
M2_DISABLE1: P1.56 (W_DISABLE1), U1.M6 (PL38A/+)
M2_DISABLE2: P1.54 (W_DISABLE2), U1.M5 (PL36B/-)
M2_REFCLK0+: P1.47 (REFCLK0+), U10.6 (DIFF1+)
M2_REFCLK0-: P1.49 (REFCLK0-), U10.7 (DIFF1-)
M2_RX0+: P1.35 (PER0+), U1.A13 (SD0_TXDP/+)
M2_RX0-: P1.37 (PER0-), U1.A12 (SD0_TXDN/-)
M2_TX0+: P1.41 (PET0+), U1.A16 (SD0_RXDP/+)
M2_TX0-: P1.43 (PET0-), U1.A15 (SD0_RXDN/-)
M2_~RST: P1.52 (~PERST0), U1.M4 (PL36A/+)
NX_REFCLK+: U1.C12 (SD_REFCLKP), U10.8 (DIFF2+)
NX_REFCLK-: U1.C11 (SD_REFCLKN), U10.9 (DIFF2-)
unnamed: C15.2, C21.2, FB1.1, U1.D2 (VCCADPHY0)
unnamed: C16.2, C22.2, FB2.1, U1.C4 (VCCDPHY0)
unnamed: C17.2, C23.2, FB3.1, U1.B5 (VCCPLLDPHY0)
unnamed: C18.2, C24.2, FB4.1, U1.C7 (VCCADPHY1)
unnamed: C19.2, C25.2, FB5.1, U1.C5 (VCCDPHY1)
unnamed: C20.2, C26.2, FB6.1, U1.C9 (VCCPLLDPHY1)
unnamed: C31.1, U2.6 (CT)
unnamed: C69.1, U8.10 (REGOUT)
unnamed: C71.2, C77.2, FB7.1, U1.C13 (VCCPLLSD0)
unnamed: C72.1, C73.1, FB8.1, U1.B11 (VCCAUXSD)
unnamed: C74.1, C75.1, C76.1, FB9.1, U1.B13 (VCCSD0), U1.B15 (VCCSD0)
unnamed: C78.1, U10.3 (XIN), Y1.1
unnamed: C79.1, C80.1, FB10.2, U10.1 (Vdd), U10.10 (Vdd)
unnamed: C81.1, U10.2 (XOUT), Y1.3
unnamed: D1.2 (BK), D2.2 (BK), D4.2 (BK), D6.2 (BK), D7.2 (BK), R22.1
unnamed: D1.3 (GK), D2.3 (GK), D3.3 (GK), D4.3 (GK), D6.3 (GK), D7.3 (GK), R21.1
unnamed: D1.4 (RK), D2.4 (RK), D3.4 (RK), D4.4 (RK), D6.4 (RK), D7.4 (RK), R20.1
unnamed: D5.2 (A), R18.2
unnamed: D8.1 (K), Q1.3 (D)
unnamed: D8.2 (A), R23.2
unnamed: L1.2, U2.15 (SWP2)
unnamed: L2.2, U2.1 (SWP1)
unnamed: L3.1, U2.11 (SWN)
unnamed: L4.1, U4.6 (SW)
unnamed: L5.1, U5.6 (SW)
unnamed: L6.1, U6.6 (SW)
unnamed: LCD1.30 (MTP), TP1.1
unnamed: P1.55 (~PEWAKE0), R29.2
unnamed: R1.2, U2.5 (SELP2)
unnamed: R3.1, U1.D11 (PT74A/+/INITN)
unnamed: R4.1, U1.E11 (PT74B/-/PROGRAMN)
unnamed: R5.2, U1.E19 (JTAG_EN)
unnamed: R8.2, U4.8 (PG)
unnamed: R9.2, U5.8 (PG)
unnamed: R10.2, U6.8 (PG)
unnamed: R11.2, R12.1, U4.2 (FB)
unnamed: R13.2, R14.1, U5.2 (FB)
unnamed: R15.2, R16.1, U6.2 (FB)
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

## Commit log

2021-01-30 Initial commit; empty project
    [mr-mainboard.kicad_pcb, mr-mainboard.kicad_sch]
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2021-01-30 Core power, disp and camera wiring
    [fpga_pwr.kicad_sch, mipi.kicad_sch, mr-mainboard.kicad_sch]
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2021-01-30 Connecting up various bits
    [conn.kicad_sch, fpga_pwr.kicad_sch, misc.kicad_sch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]
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2021-01-30 Annotate and assign some footpints
    [conn.kicad_sch, dram.kicad_sch, fpga_io.kicad_sch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]
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2021-01-31 Add and assign more footprints
    [conn.kicad_sch, fpga_io.kicad_sch, fpga_pwr.kicad_sch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]
2021-01-31 First pass at placement
    [conn.kicad_sch, mipi.kicad_sch, misc.kicad_sch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]
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2021-02-03 First pass at routing done
    [fpga_io.kicad_sch, mr-mainboard.kicad_sch]
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2021-02-18 Working on debug/IO board
    [mr-ioboard.kicad_sch]
2021-02-18 Add USBC controller and ESD diodes
    [mr-ioboard.kicad_sch]
2021-02-19 Schematic for ear board
    [mr-ear.kicad_pcb, mr-ear.kicad_sch]
2021-02-19 Add WiFi module to IO board
    [mr-ioboard.kicad_sch]
2021-02-24 Assign some footprints & fix values for IO board
    [mr-ioboard.kicad_sch]
2021-02-24 Create some footprints for the IO board
    [mr-ioboard.kicad_sch]
2021-02-24 Initial IO board layout
    [mr-ioboard.kicad_pcb, mr-ioboard.kicad_sch]
2021-02-24 Add a few missing parts to IO board
    [mr-ioboard.kicad_pcb, mr-ioboard.kicad_sch]
2021-02-25 Fix IO board 2.5V supply
    [mr-ioboard.kicad_pcb, mr-ioboard.kicad_sch]
2021-02-25 Add VLED buck regulator to IO board
    [mr-ioboard.kicad_pcb, mr-ioboard.kicad_sch]
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2021-03-03 First pass at routing IO board
    [mr-ioboard.kicad_pcb]
2021-03-03 Tidy up IO board silk
    [mr-ioboard.kicad_pcb]
2021-03-03 Some tidying up of IO board
    [mr-ioboard.kicad_pcb, mr-ioboard.kicad_sch]
2021-03-17 Fix side of connector on IO board
    [mr-ioboard.kicad_pcb]
2021-03-24 mainboard: Fix some schematic ERC issues
    [conn.kicad_sch, dram.kicad_sch, fpga_io.kicad_sch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]
2021-03-24 Fix ERC/DRC issues on mainboard PCB
2021-03-24 Fix IO board ERC/DRC issues
    [mr-ioboard.kicad_pcb, mr-ioboard.kicad_sch]
2021-03-24 Add mounting holes to IO board
    [mr-ioboard.kicad_pcb, mr-ioboard.kicad_sch]
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2021-03-27 Add LRADC buttons to IO board
    [mr-ioboard.kicad_pcb, mr-ioboard.kicad_sch]
2021-03-27 Use B3U-3000P for all buttons
    [conn.kicad_sch, mr-ioboard.kicad_pcb, mr-ioboard.kicad_sch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]
2021-04-09 Use 3-pin connector for ears
    [conn.kicad_sch, fpga_io.kicad_sch, mr-mainboard.kicad_sch]
2021-04-10 Replace TPS62823 with AP3402 in schematics due to supply issues
    [mr-ioboard.kicad_sch, mr-mainboard.kicad_sch, power.kicad_sch]
2021-04-10 Replace Vbus regs with AP64501 in schematics due to supply issues
    [mr-ioboard.kicad_sch]
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2021-04-13 Update IO board PCB layout with new regs
    [mr-ioboard.kicad_pcb]
2021-04-18 Update ear board with addressable LEDs
    [mr-ear.kicad_sch]
2021-04-19 Update some inductor part numbers
    [mr-ioboard.kicad_pcb, mr-ioboard.kicad_sch, mr-mainboard.kicad_sch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]
2021-04-19 Update some part numbers
    [conn.kicad_sch, fpga_io.kicad_sch, misc.kicad_sch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]
2021-10-23 Fresh start with a new K26 based project
    [conn.kicad_sch, dram.kicad_sch, fpga_io.kicad_sch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]
2021-10-23 Pin planning PS IO
    [meowality_top.kicad_sch, som.kicad_sch]
2021-10-24 Power and MIPI pin planning
    [meowality_top.kicad_sch, som.kicad_sch]
2021-10-26 Add basic power rails
    [meowality_top.kicad_sch, power.kicad_sch]
2021-10-26 Add microdisplay and its power supply
    [meowality_top.kicad_sch, microdisplay.kicad_sch]
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2021-11-08 Pin planning the main b2b connectors
    [b2b.kicad_sch, meowality_top.kicad_sch, power.kicad_sch]
2021-11-11 Initial pin plan for front b2b connector
    [b2b.kicad_sch, meowality_top.kicad_sch]
2021-11-11 Begin front board schematic
    [meowality_front.kicad_pcb, meowality_front.kicad_sch]
2021-11-12 SD card, ULPI PHY, JTAG/UART
    [b2b.kicad_sch, meowality_top.kicad_sch, soc_periph.kicad_sch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]
2021-11-18 Add PCIe and camera to front board
    [b2b.kicad_sch, meowality_front.kicad_sch, meowality_top.kicad_sch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]
2021-11-20 Add some general control IO
    [b2b.kicad_sch, meowality_top.kicad_sch, som.kicad_sch]
2021-11-20 Add skeleton of left IO board
    [b2b.kicad_sch, meowality_io.kicad_pcb, meowality_io.kicad_sch]
2021-11-20 Add USB hub and UART ICs
    [meowality_io.kicad_sch]
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2021-11-20 Add Vbus to 5V buck
    [meowality_io.kicad_sch]
2021-11-21 Add type-C mux; IO exp; 3.3V/1.8V rails
    [meowality_io.kicad_sch]
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2021-11-21 Connecting some misc SoM IO
    [b2b.kicad_sch, meowality_top.kicad_sch, som.kicad_sch]
2021-11-22 Fixing various top board issues
    [b2b.kicad_sch, meowality_top.kicad_sch, microdisplay.kicad_sch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]
2021-11-22 Fixing various IO board issues
    [meowality_io.kicad_sch]
2021-11-23 Fixing various front and top board issues
    [b2b.kicad_sch, meowality_front.kicad_sch, meowality_top.kicad_sch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]
2021-11-23 Fix MPSoC pinout issues
    [som.kicad_sch]
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2021-11-28 Assign most top-board footprints
    [b2b.kicad_sch, meowality_io.kicad_sch, meowality_top.kicad_pcb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]
2021-11-29 Replace type-C power with good ol' barrel jack
    [b2b.kicad_sch, meowality_io.kicad_sch, microdisplay.kicad_sch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]
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2022-01-12 Re-add USB-C PD control
    [io.kicad_sch, meowality-main.kicad_sch, periph.kicad_sch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]
2022-01-13 ERC fixes
    [io.kicad_sch, lcd_cam.kicad_sch, meowality-main.kicad_sch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]
2022-01-13 Add some footprint mappings
    [io.kicad_sch, lcd_cam.kicad_sch, meowality-main.kicad_sch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]
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2022-01-14 Footprint assignments and related fixes
    [io.kicad_sch, lcd_cam.kicad_sch, meowality-main.kicad_sch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]
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2022-01-14 Rework power arch to add 3V3PL; 5x PL RGB LEDs
    [io.kicad_sch, lcd_cam.kicad_sch, meowality-main.kicad_sch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]
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2022-01-14 Outline floorplan and design rule setup
    [meowality-main.kicad_pcb]
2022-01-15 Add separate reg for 3V3PL
    [lcd_cam.kicad_sch, meowality-main.kicad_sch, periph.kicad_sch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]
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2022-01-16 Add TVS on 5V and Vbus
    [meowality-main.kicad_pcb, meowality-main.kicad_sch, power.kicad_sch]
2022-01-23 Mechanical updates; add cam clk connectors
    [lcd_cam.kicad_sch, meowality-main.kicad_pcb, meowality-main.kicad_sch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]
2022-01-30 Fix LCD connector rotation
    [meowality-main.kicad_pcb]
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2022-02-02 First pass high-speed routing
    [meowality-main.kicad_pcb, som.kicad_sch]
2022-02-12 High speed bits routed
    [meowality-main.kicad_pcb]
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2022-02-13 Route and pinswap PL LEDs
    [meowality-main.kicad_pcb, som.kicad_sch]
2022-02-16 Tidy up power routes
    [meowality-main.kicad_pcb]
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2022-02-18 Debug signal pinswaps and routing
    [io.kicad_sch, meowality-main.kicad_pcb, power.kicad_sch]
2022-02-20 USB and other misc routing
    [io.kicad_sch, meowality-main.kicad_pcb, power.kicad_sch]
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2022-03-06 Fixup Kria footprint
    [power.kicad_sch, som.kicad_sch]
2022-03-29 Rework LCD PWM setup
    [lcd_cam.kicad_sch, meowality-main.kicad_sch, power.kicad_sch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]
2022-05-01 Fix some ERC/DRC issues
    [lcd_cam.kicad_sch, meowality-main.kicad_sch, periph.kicad_sch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]
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
